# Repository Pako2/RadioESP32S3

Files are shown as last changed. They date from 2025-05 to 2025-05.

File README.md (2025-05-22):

# RadioESP32S3
## Introduction
&nbsp;&nbsp;&nbsp;&nbsp;Some time ago I published the [RadioESP32](https://github.com/Pako2/RadioESP32) project. It was intended exclusively for the basic ESP32 chips. I realized that it would be good to also try a variant with the more modern ESP32-S3 chip and this is the result. Since almost everything is identical to the original project, I will mainly emphasize the differences here.\
&nbsp;&nbsp;&nbsp;&nbsp;Complete project documentation can be found in the [UserGuide_EN.pdf](doc/UserGuide_EN.pdf) file.

## How to install
Experienced Tinkerers who have installed VS Code with PlatformIO supplement and normally use it probably do not need any other advice. Everything is described in the previous text. However, there may be some less experienced users who are interested in trying the project and do not need to make their own modifications. In this case, they can use pre-compiled binaries and install them in ESP32-S3 without VS Code/Platformio.
The procedure is as follows (valid only to Windows users):
1. The default assumption is that the development kit is connected to the USB port of your computer and you know the number of (virtual) COM port. Suppose it's a *COM10*. Use the connector marked *COM* (not *USB*) on the development kit.
2. Download the latest [RadioESP32S3_binaries.zip](https://github.com/Pako2/RadioESP32S3/releases/latest/download/RadioESP32S3_binaries.zip) and unpack the ZIP file to some suitable (work) folder.
3. In the selected folder, the **bin** folder appears that contains everything you need.
4. Open the command line window (**cmd.exe**) so that you are in the above folder **bin**.
5. Enter the **flash.bat** command. The following offer should appear:
<p float="left">
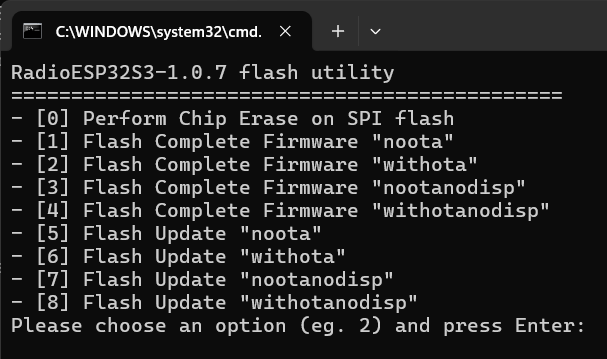
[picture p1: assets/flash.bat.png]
Flash menu
  
</p>

6. Select the desired firmware version (ie press the appropriate number) and then press Enter.
7. You will then be prompted to enter a COM port. Write the corresponding name (by example in point **1** it would be *COM10*) and press Enter.
8. There should be installed the necessary SW into ESP32.
9. After completion you can continue according to the **First start** chapter.

<ins>Note:</ins>\
The *withota* and *withotanodisp* versions are intended for production use, while the *noota* and *nootanodisp* versions are intended primarily for the development phase (as they allow comfortable editing of web server files). However, there is nothing to prevent the *noota* and *nootanodisp* versions from being used for production use as well.

## First start
When the device is started for the first time, it runs in default settings and in AP mode. On the PC, connect to the **RadioESP32S3** network and in the browser to the address **192.168.4.1**. A web page should appear through which the device settings need to be made.

## Design of the device
The circuit diagram and printed circuit board were created using the Eagle design system.
### Wiring diagram
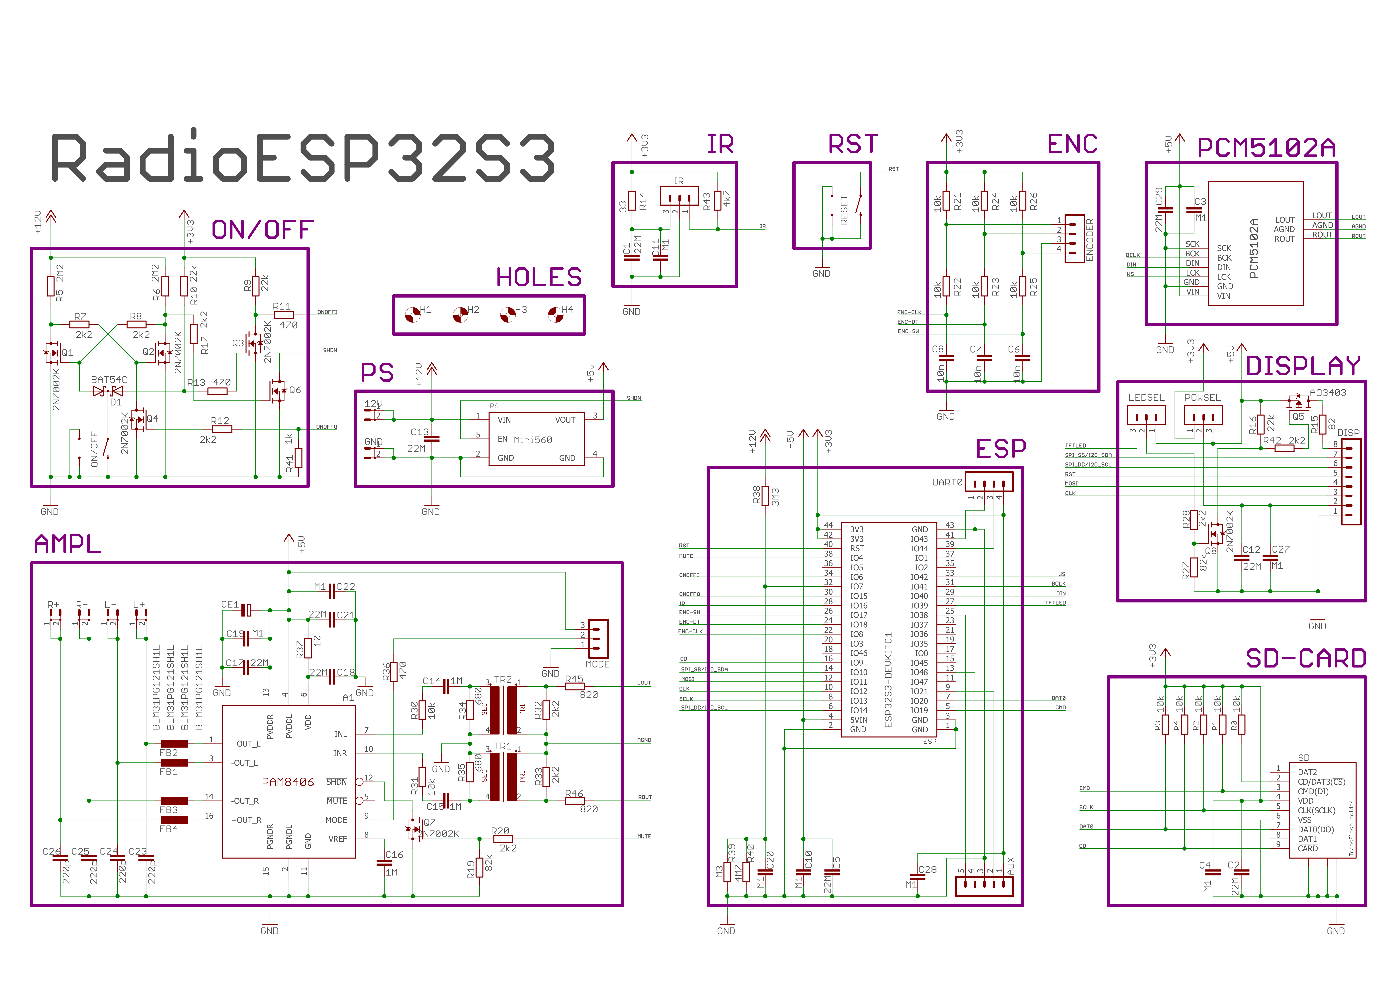
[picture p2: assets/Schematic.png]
Wiring diagram

### Printed circuit board
<p float="left">
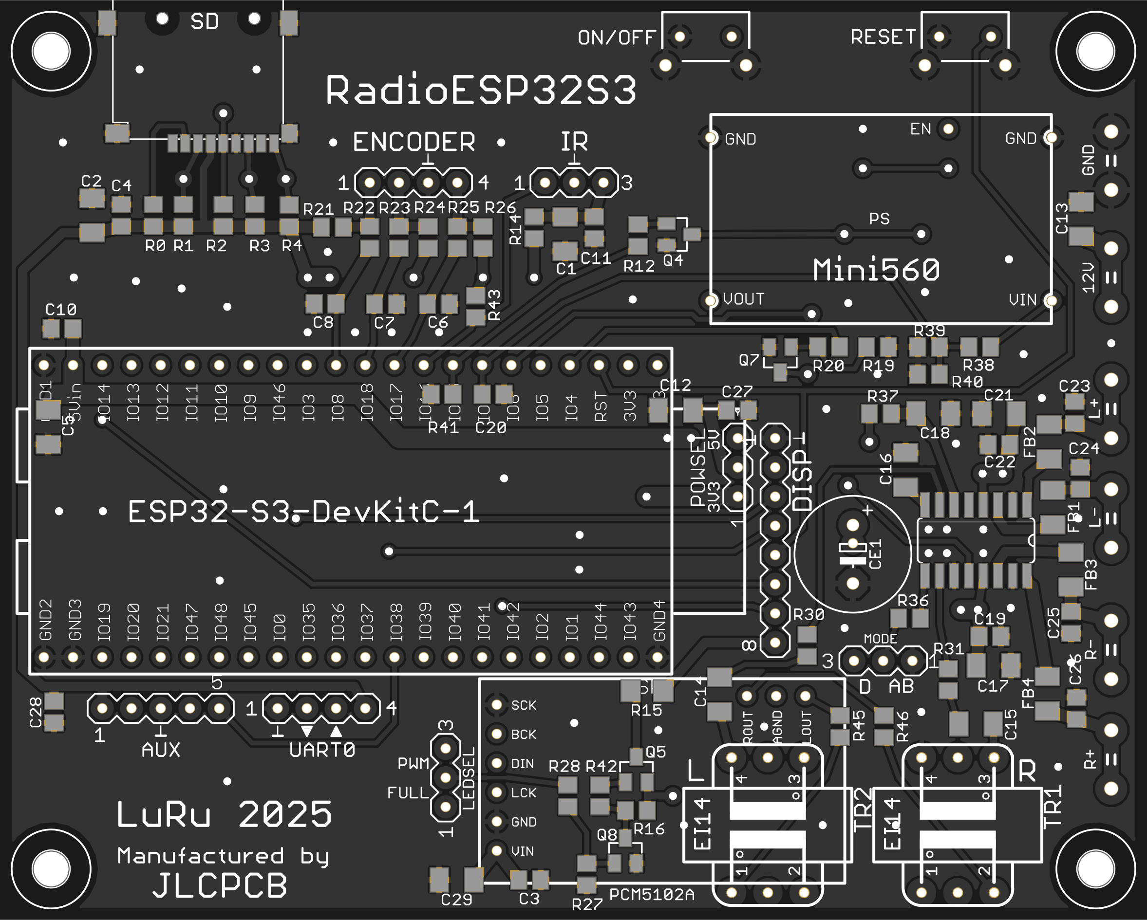
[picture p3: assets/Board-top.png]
PCB top side
  
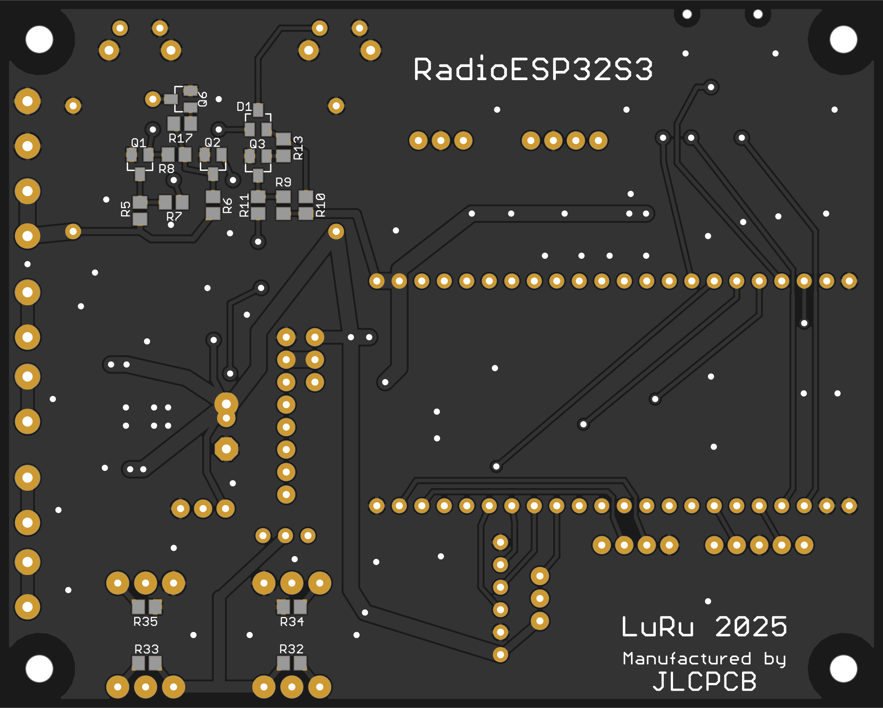
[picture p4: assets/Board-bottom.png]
PCB bottom side
   
</p>

## Choice of components
The basis of the design is the development kit "ESP32-S3-DevKitC-1" (shorter wider version). The board must have at least 8MB of flash memory and 4MB of PSRAM memory.

<p float="left">
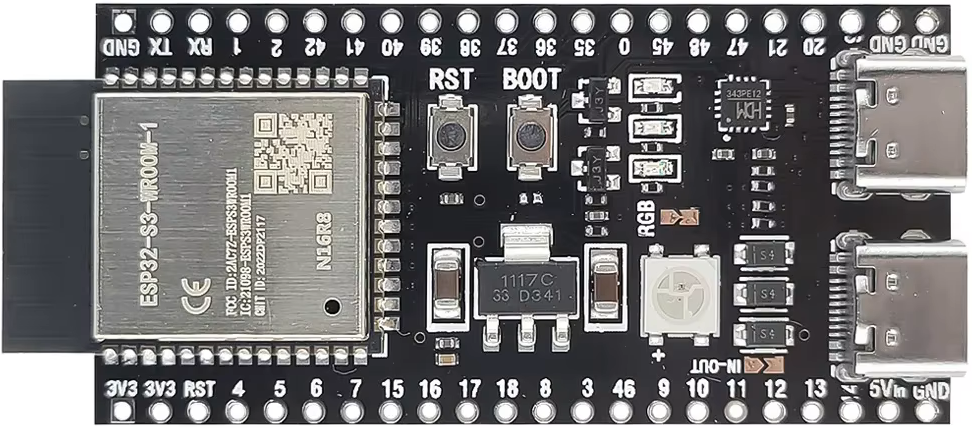
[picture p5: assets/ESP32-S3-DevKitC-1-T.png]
Development board - top side
   
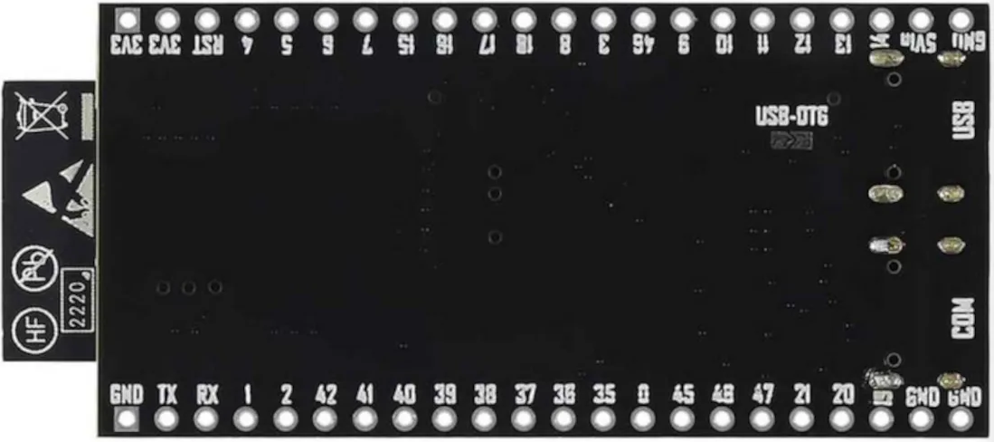
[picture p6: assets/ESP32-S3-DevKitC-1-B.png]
Development board - bottom side
   
</p>

## Choice of GPIO
I designed and used a PCB where the assignment of GPIOs for various functions is therefore fixed. But this is not fixed in the software. In fact, it is the opposite, most GPIOs can be selected by the user, so it should be easy to use a different connection than the PCB I designed.
However, there are two exceptions:
1. Display connection - this must be set in the *platformio.ini* file before compilation.
2. Selection of ADC channel for battery measurement (I chose channel adc1-6, which corresponds to GPIO 7)

<ins>Note:</ins>\
In the original design with the ESP32 base chip, there is a third exception - connecting an SD card in SD_MMC mode. Fortunately, there is no such exception here, because in this case (ESP32-S3 chip) any GPIO pin can be used. This is of course a huge advantage, because the problems that were with the ESP32 base chip (there GPIO2, which is one of the bootstrapping pins, had to be used) have disappeared.

## Assembled board
Finally, you can see a few pictures of the printed circuit board completely assembled and including the installed subboards (ESP32 development kit and DAC). I also added one photo of the finished radio (without the cover).

PCB 1
PCB 2
PCB 3
PCB 4
PCB 5
PCB 6
RADIO

### License
The code parts written by the author of the **RadioESP32S3** project are licensed under [GPL-3.0](LICENSE), 3rd party libraries that are used by this project are licensed under different license schemes, please check them out as well.

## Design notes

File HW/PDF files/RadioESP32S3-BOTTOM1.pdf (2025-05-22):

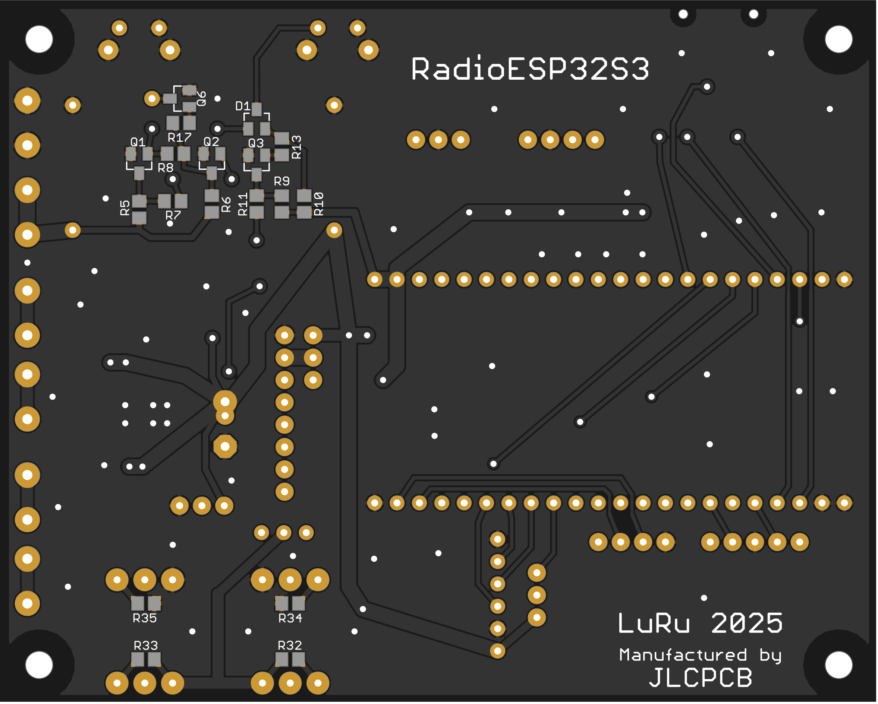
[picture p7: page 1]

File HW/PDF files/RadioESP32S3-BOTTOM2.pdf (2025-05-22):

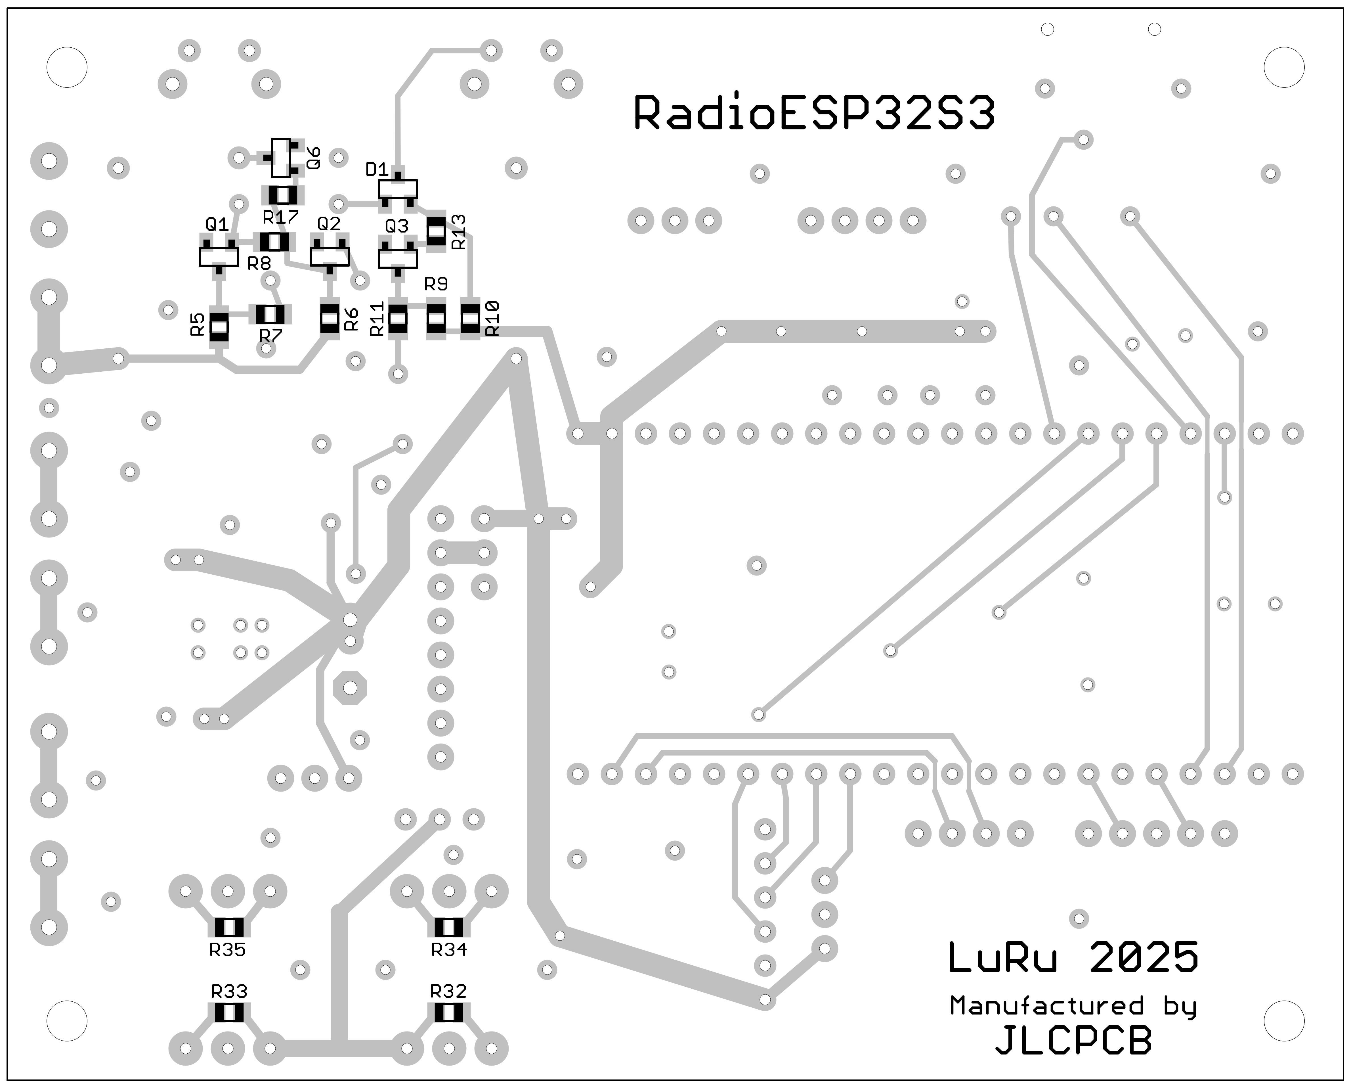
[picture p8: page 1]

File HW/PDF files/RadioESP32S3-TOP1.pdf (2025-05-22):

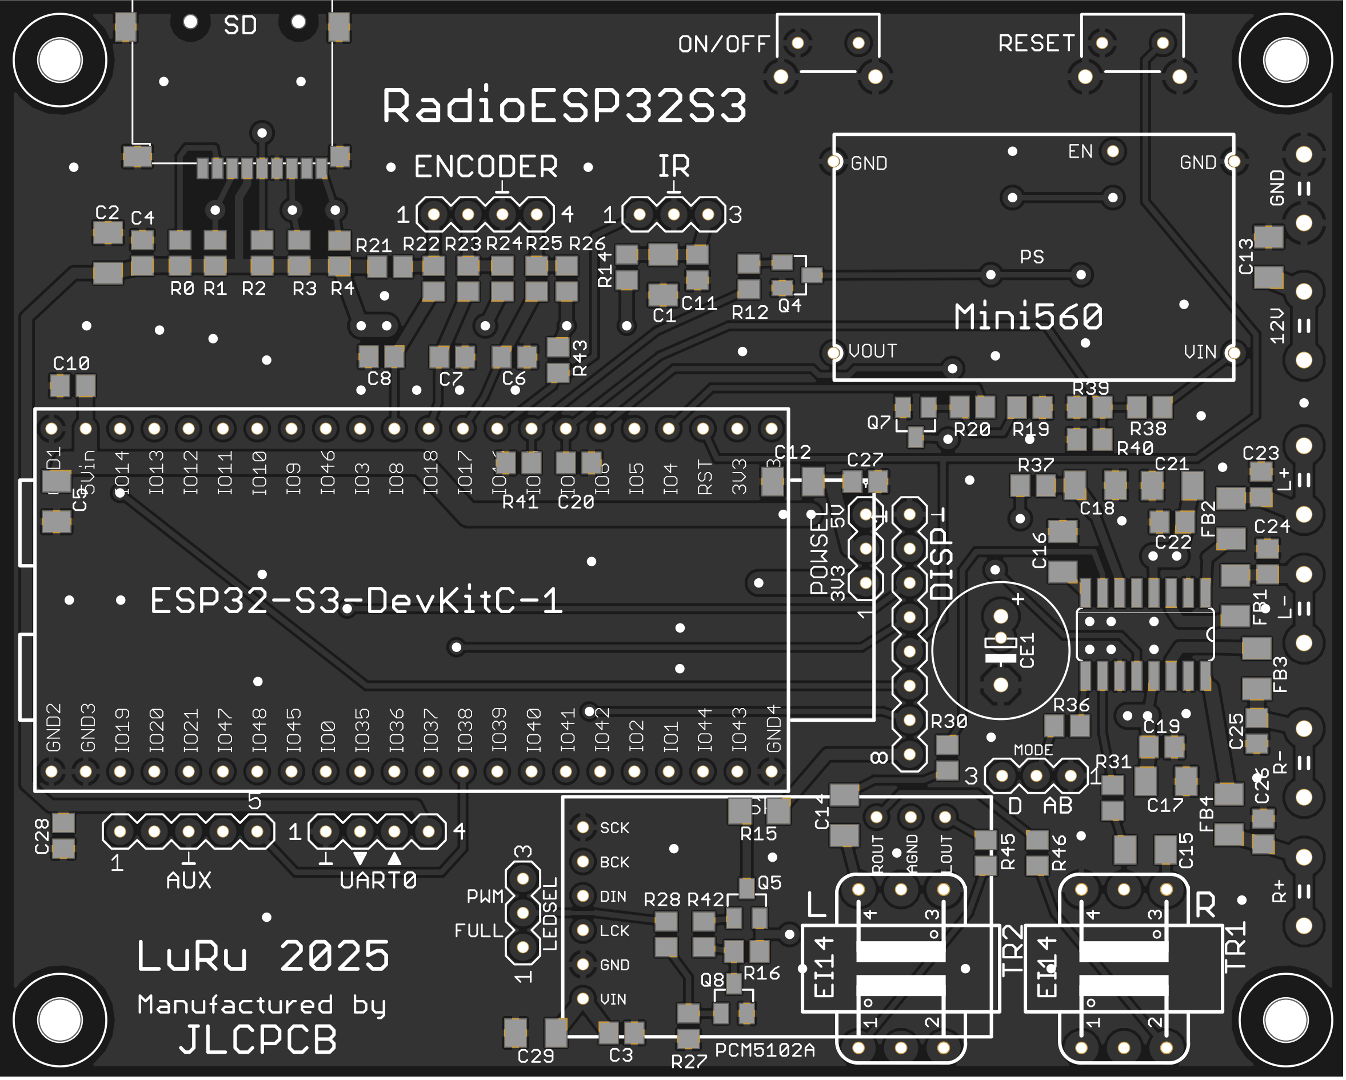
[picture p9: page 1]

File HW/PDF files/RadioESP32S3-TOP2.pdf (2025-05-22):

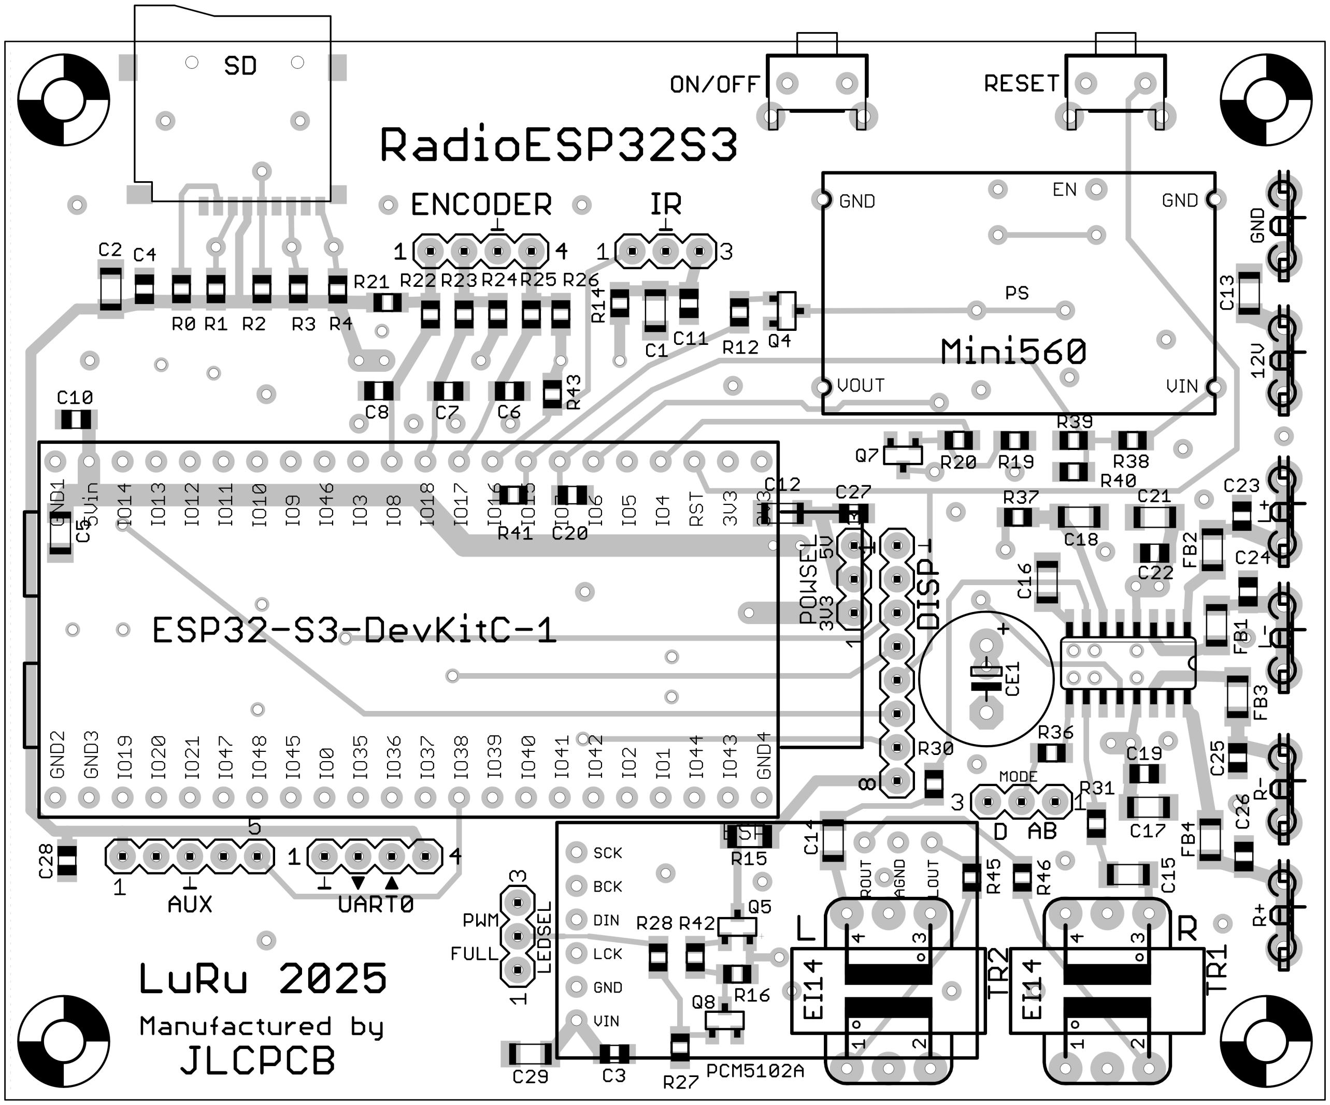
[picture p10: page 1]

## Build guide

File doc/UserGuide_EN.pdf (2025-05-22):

## RadioESP32S3

## Introduction

First of all, it is worth mentioning that this project would probably never have been created without the popular project "ESP32Radio-V2" by Edzelf. I am very grateful to the author for it and thank him for his work. Originally, of course, I took over the original project in its unchanged form, but very soon it stopped being convenient for me. I especially disliked the fact that the display did not display characters with diacritics.
The second biggest problem for me was the functioning of the file player from the SD card. One of my requirements for the device was that it should allow listening to audiobooks. In this case, however, the files need to be played in a defined (i.e. alphabetical) order. But that did not work with the original SW. After copying the files from the HDD to the SD card, the files were always arranged in a kind of random order and listening to the individual parts in the correct order was very complicated (the correct part had to be selected manually).
In addition to the two problems mentioned above, there were a number of other small things that I imagined to work differently. For example, I can mention a function that ensured that the last station listened to was always played after switching on (and with the last volume level used). But that did not suit me at all, I prefer that a default station (with the default volume) be played after switching on the device. I also planned to add some new functions that the original design did not have. In particular, I wanted the radio to be able to be turned on and off by pressing one (same) button and for the radio to have a sleep function (i.e. automatic shutdown after a set time). Despite the above facts, I took over several things from the original "ESP32Radio-V2" project almost unchanged and my work was thus made easier.
The website design, the way the ESP32-S3 communicates with the computer (via a web browser), and a few other solutions (like how to upgrade or work with the configuration file) are taken from the esp-rfid project. I have used it in several projects and it exactly suits my needs and ideas.

## Development with VS Code and PlatformIO

I use VS Code/PlatformIO as a development environment. Using the platformio.ini file, it is possible to create several software variants by specifying or not specifying the so-called "build-flag". The DATAWEB, SDCARD, BATTERY, AUTOSHUTDOWN and OTA build-flags are particularly important.
- Using the DATAWEB build-flag, the SW is compiled in a version that has the web server files stored in the "LittleFS" file system area, while without the DATAWEB parameter, the SW is compiled in a version in which the web server files are stored in the program memory (using the PROGMEM attribute) in the form of variables. I call the first version „data“ for short, the second „webh“. The data variant is intended primarily for the development phase (but nothing prevents it from being used as a production one), while the webh variant is intended exclusively as a production one and it is more or less impossible to develop with it.
- Using the SDCARD build-flag, support for the SD card file player function is enabled. Without using the aforementioned build-flag, the device is only able to play radio stations.
- Using the BATTERY build-flag, support for the supply voltage measurement function is enabled. This is of course suitable in the case of battery power. The display then shows the charge level.
- Using the AUTOSHUTDOWN build-flag, the support of the function that allows the device to be turned on and off with one button and also the sleep function (adjustable automatic shutdown time) is enabled. Of course, the condition is that the HW is equipped with the necessary circuit.
- Using the OTA build-flag, the function that allows a comfortable upgrade from the web interface is enabled. See the Upgrade chapter.
4 types of “envs” are also prepared in the platformio.ini file. With them, you can select both the SW variant (development, i.e. data – without OTA and production, i.e. webh – including OTA) and the variant with or without display. So, 4 combinations in total (noota, withota, nootanodisp and withotanodisp). The relevant “env” version is selected by commenting/uncommenting in the [platformio] section.
- 1 -

Using the DATAWEB build-flag, I proceed as follows when developing the SW:
1) Development takes place exclusively in the software data variant (the DATAWEB build-flag is used in the platformio.ini file – „env“ is either noota or nootanodisp). After editing the source files, compilation is performed in the usual way and the device is upgraded via the USB (serial) port.
2) If it is necessary to edit the *.html or *.js files of the web server to fix or add a function, you need to open the page http://<IP address of the device>/edit. For this to work, the PC must be connected to the Internet. The online library "ace" (Ajax.org Cloud9 Editor) is used for editing. For more information, see https://ace.c9.io/.
3) Once the required functionality has been achieved using steps 1 and 2, the webh variant of the software can be created. This is done by running the user script Download FS & Create WEBH, which is available via the PROJECT TASKS/<selected env version>/Custom menu. This will transform the web server files (from the LittleFS file system) into webh files. The utility "pio-esp32-esp8266-filesystem-downloader" by maxgerhardt is used to download the file system image and extract it.
4) Switch to webh variant (in the platformio.ini file, the build-flag DATAWEB needs to be removed [commented out] – „env“ is either withota or withotanodisp) and compile. The resulting image “firmware_WEBH_X.X.X.bin” (created during the compilation process) can be found in the /bin/<selected env version> directory. The version designation “X.X.X” is also set as a “build-flag” in the platformio.ini file before compilation.

## Upgrade

A device running the webh firmware variant can be upgraded very easily via the web interface. Procedure:
a) Select the Update item in the menu (on the left side of the screen).
b) A window will appear, showing the current version approximately in the middle.
c) Use the “Select file” button to search for the firmware file on your computer (e.g. firmware_WEBH_1.0.0.bin) and start the process with the Update button.
If everything goes well, the device will already contain the new software version after the restart.

## First start

When the device is started for the first time, it runs in default settings and in AP mode. On the PC, connect to the "RadioESP32S3" network and in the browser to the address 192.168.4.1. A web page should appear through which the device settings need to be made.

## Main menu

There is always the main menu on the left side of the screen. Description of the main menu items:

Radio Player
After clicking on this item, a page appears with which you can comfortably control the radio.

SD Card Player
This item is only displayed if the SW is compiled with the SDCARD option.
After clicking on this item, a page appears with which you can comfortably control the functions of the SD Card Player.
Status
Clicking on this item will bring up a page with basic device information.
- 2 -

Settings
If you need to adjust the device settings (for example, when you first start it), select Settings. Clicking on it will expand the menu and you will see eight submenus:

Radio Settings
This page is used to create a radio station menu. You can also set the default station (it is always automatically selected when the device is turned on), the default volume, and the values of a simple equalizer.

SD Card Settings
This item is only displayed if the SW is compiled with the SDCARD option. Only one parameter can be set on this page, and that is "Seek step". This is the length of the jump (forward and backward) in seconds. The default volume and equalizer settings on the Radio Settings page also apply to the SD card file player.
Network Settings
On this page, you need to set the network (or multiple networks) to which the device is to connect. Click Edit Networks and then New Network. In the dialog box that appears, set the required values. You can use the Scan button to search for available networks. After setting, click Save Changes. Under the network table, you can also change the SSID, IP address and mask (all in AP mode). You need to confirm the changes by clicking the Save button and then the yellow button with the text You have uncommited changes, please click here to commit and reboot …. However, this yellow button should only be used after going through all other settings, because after using it, the device will restart.

Hardware Settings
On this page it is possible to set some used GPIO pins (some are set before compilation in platformio.ini) and several other parameters. The set values must be confirmed again by pressing the Save button.

IR Remote Settings
This page is where you configure the remote control commands. Adding a new command is very simple and intuitive. The set commands must be confirmed again by pressing the Save button.

Display Settings

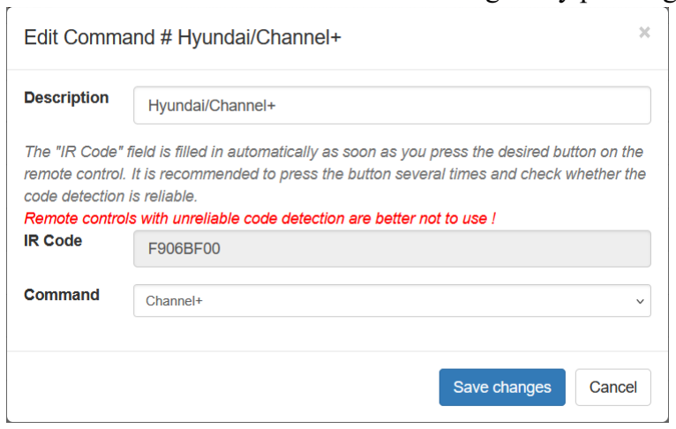
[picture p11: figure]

On this page, it is possible to set, in particular, the display backlight levels and the clock display settings in idle mode. The user can also name the days of the week in their own language (the names are English by default). As always, after all changes, the Save button must be pressed.

General Settings
On this page you can set the "Host Name" and also calibrate the battery level display. Confirm by pressing the Save button again.
- 3 -

NTP (Time) Settings
On this page you can set the NTP server, synchronization interval (in minutes) and time zone. Changes are confirmed again by pressing the Save button.
Sometimes it may happen that at the time of switching on (or restarting) the device none of the known WiFi networks are available. Then of course it is not possible to synchronize the time with the NTP server. In such an extreme situation the Sync Browser Time to Device button will help.

Backup & Restore
In the main menu we will also find the item “Backup & Restore”. The meaning is obvious from the name. It is possible to save a file with a backup of the settings to the PC and, if necessary, easily return to the same settings. Under the mentioned item there is another function – reboot the device.

Factory reset
This main menu item hides a function of the same name. After activating it, the configuration file is deleted and after rebooting the device is in the same state as when it was first started.

Update
This item is displayed only if the SW was compiled with the OTA build-flag, i.e. in the case of "envs" withota and withotanodisp. The procedure is described above in the Upgrade paragraph.

## Device design

The circuit diagram and printed circuit board were created using the Eagle design system.

Circuit diagram


- 4 -

Printed circuit board

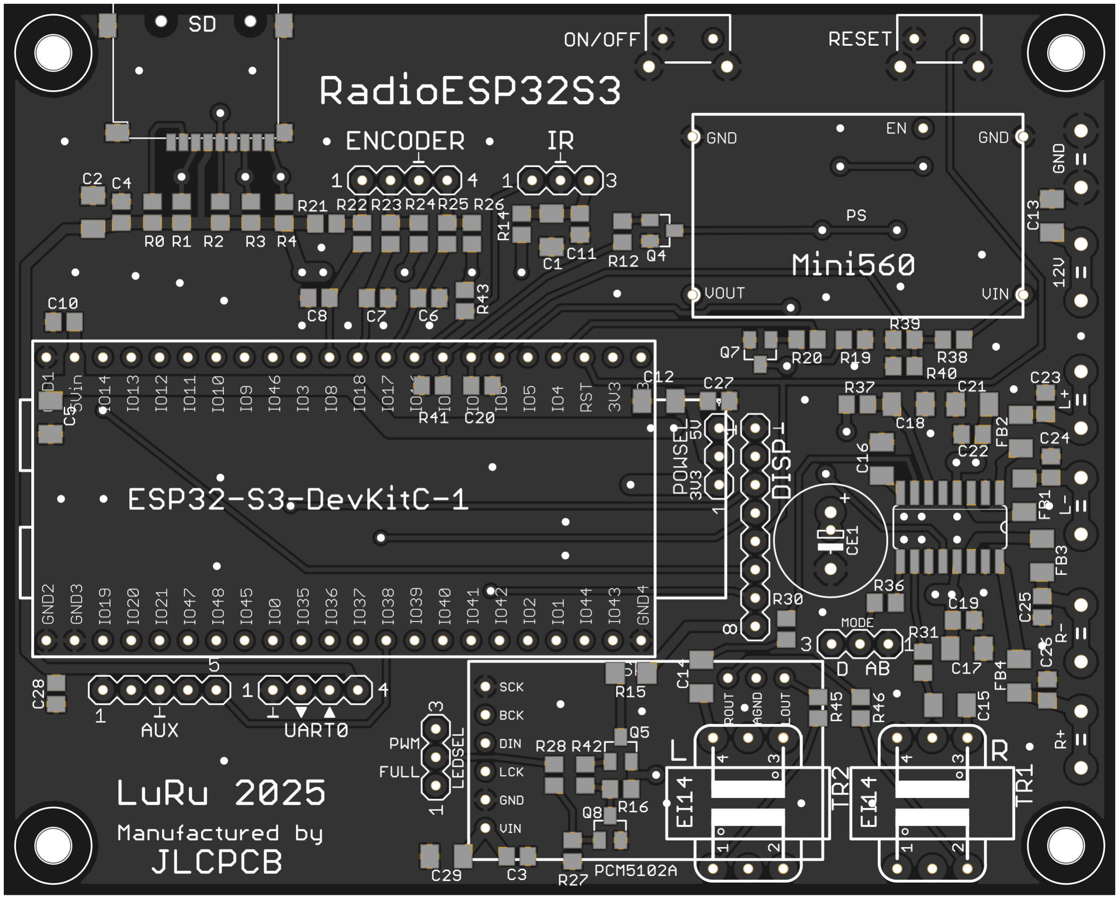
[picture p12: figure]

Component selection

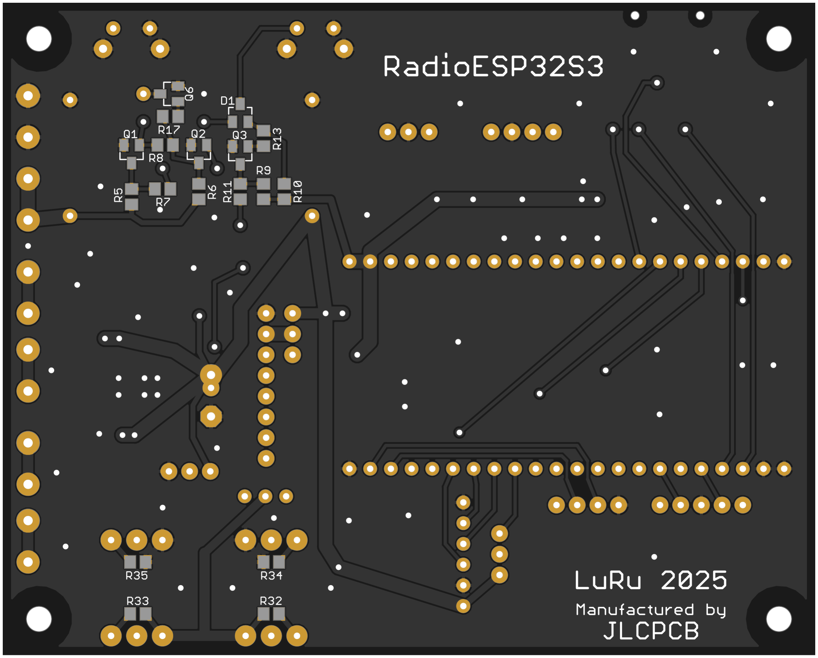
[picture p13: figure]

In the first phase of development, I used the VS1053 module (as a DAC) following Edzelf's example. It worked well, but I found this solution unnecessarily expensive and quite problematic (for example, I once accidentally bought a VS1003 instead and it didn't work well). That's why I completely abandoned this path and switched exclusively to a solution with I2S. As the basis for the SW, I chose the excellent "ESP32-audioI2S" library from the author shreibfaul1. This led to the need to use a type of ESP32-S3 development kit that is equipped with PSRAM memory (without this memory, no more complex project can be created with the "ESP32-audioI2S" library, you will soon run out of RAM) and flash memory of at least 8MB (to be able to upgrade via OTA). For this reason, I chose a development kit of the ESP32-S3-DevKitC-1 type.

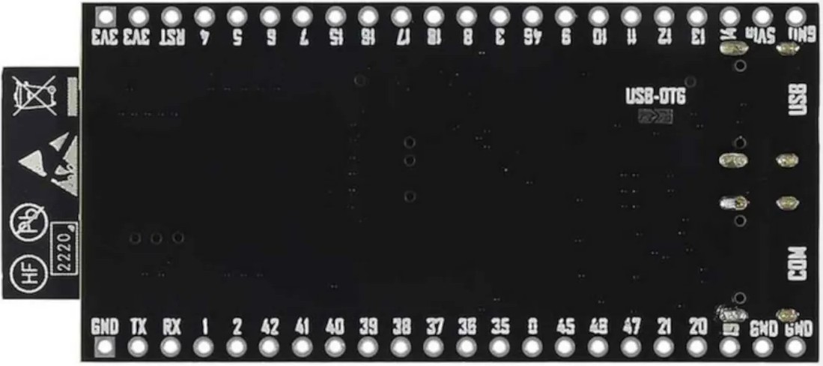
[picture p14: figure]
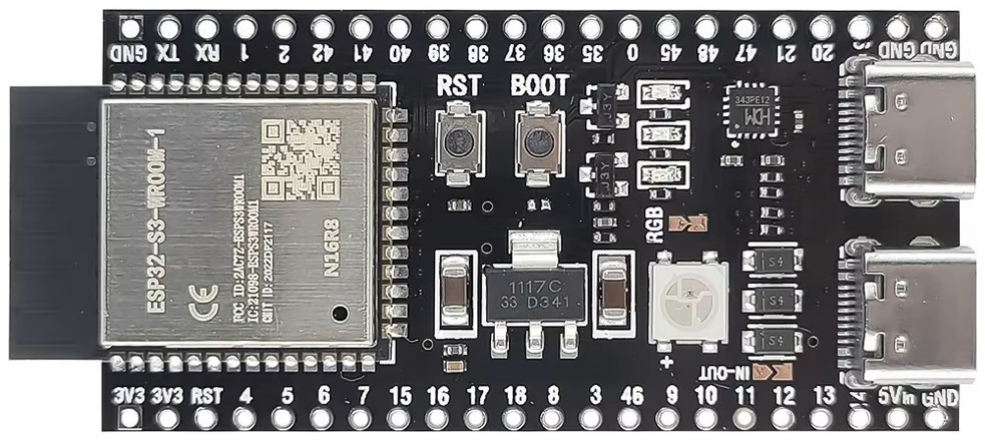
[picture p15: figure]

I decided that the basic supply voltage of the device will be 12V, because it can be very well implemented with three 18650 Li-ion cells. However, the development kit requires a voltage of 5V (as well as some other components) and therefore it is necessary to use a suitable step-down module. I chose the Mini560 module, which is sufficiently dimensioned (both voltage and current) and is equipped with an EN input (necessary for my needs).

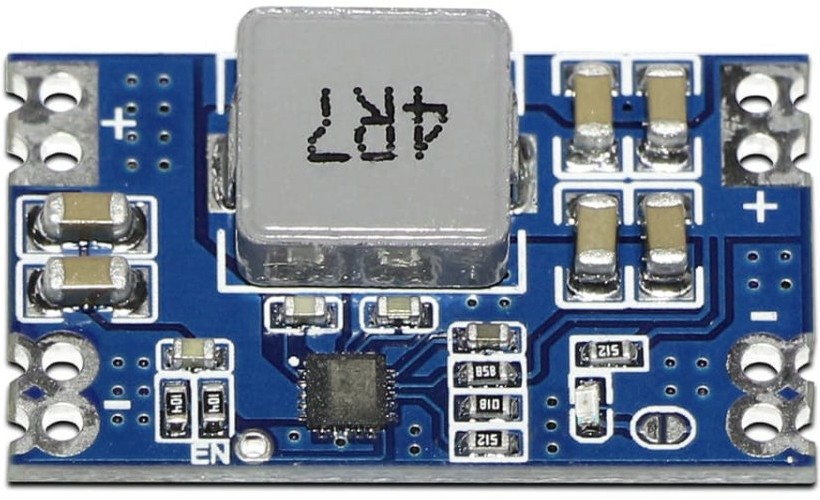
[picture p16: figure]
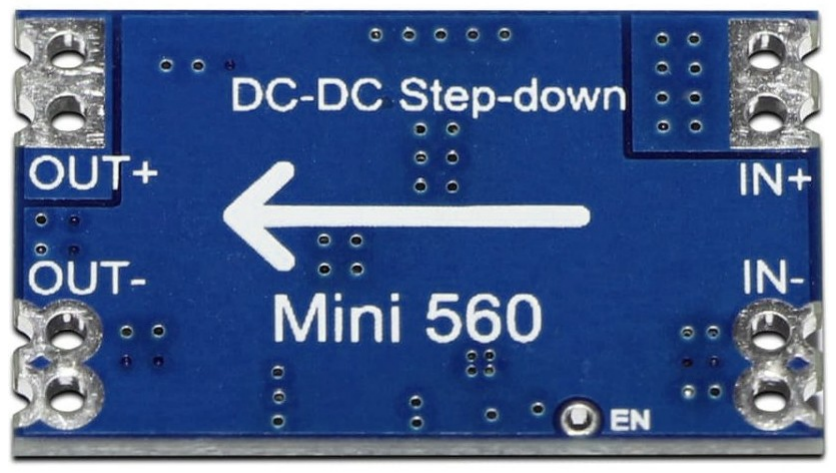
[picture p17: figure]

- 5 -

Originally (like Edzelf) I kept the option to choose between OLED and TFT display when compiling the software. But I finally gave up and OLED displays are no longer supported at all. So there are only two options - either a TFT display or none. I used a display with a diagonal of 1.77 inches and a resolution of 160x128. However, it should not be a problem to use any other one, supported by the TFT_eSPI library.

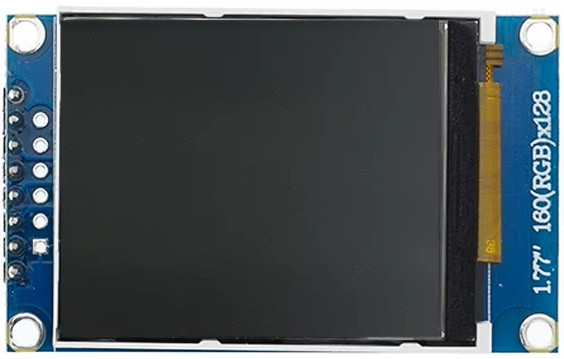
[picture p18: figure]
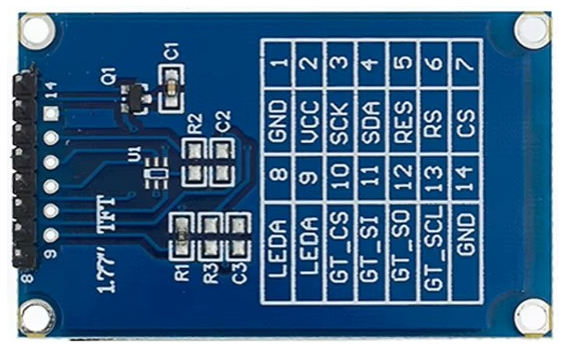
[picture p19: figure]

The essential part of the device is the digital-to-analog converter. I chose a module with the PCM5102A chip, which suited me due to its dimensions and also because the audio output is not only connected to a jack connector, but also to a pin header. This greatly simplifies the connection of the converter to the motherboard.

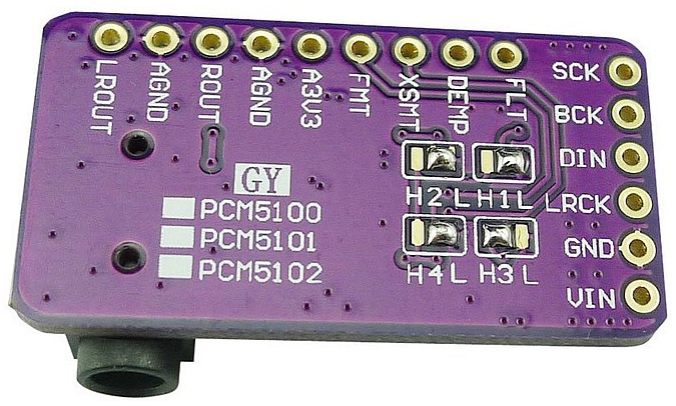
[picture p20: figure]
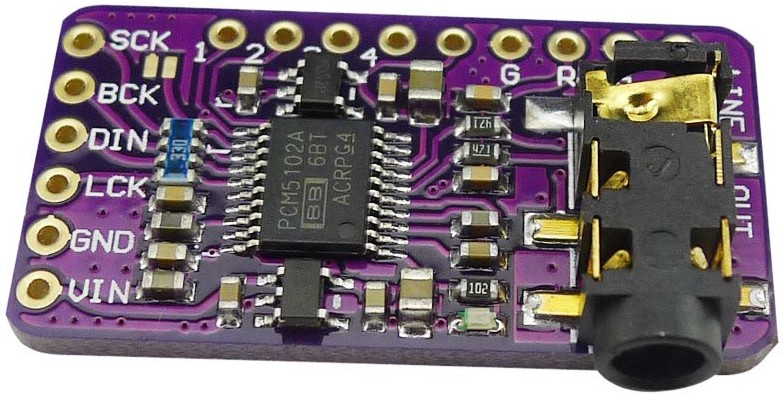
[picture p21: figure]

As an amplifier, I chose the PAM8406 type, which is powerful enough, works with a 5V supply voltage, and can be easily soldered by hand. This amplifier has one more advantage - it can operate in either class D or AB. I have kept the option of choosing on the printed circuit board as well - the mode is selected by placing the appropriate jumper.

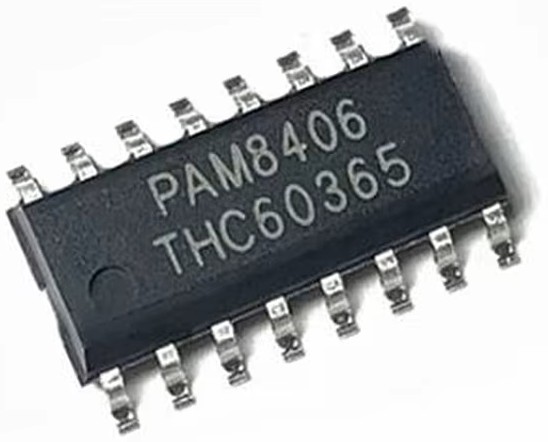
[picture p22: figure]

- 6 -

It is necessary to include isolation transformers between the DAC and the amplifier to break the ground loop and prevent unpleasant interference. I chose transformers that are only 9.1mm high and fit well between the converter board and the motherboard.

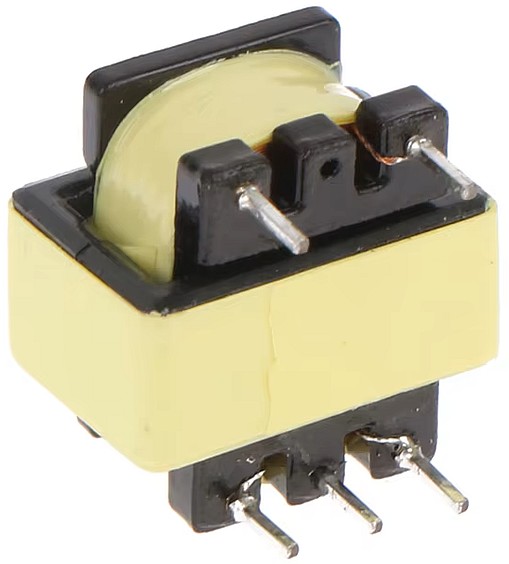
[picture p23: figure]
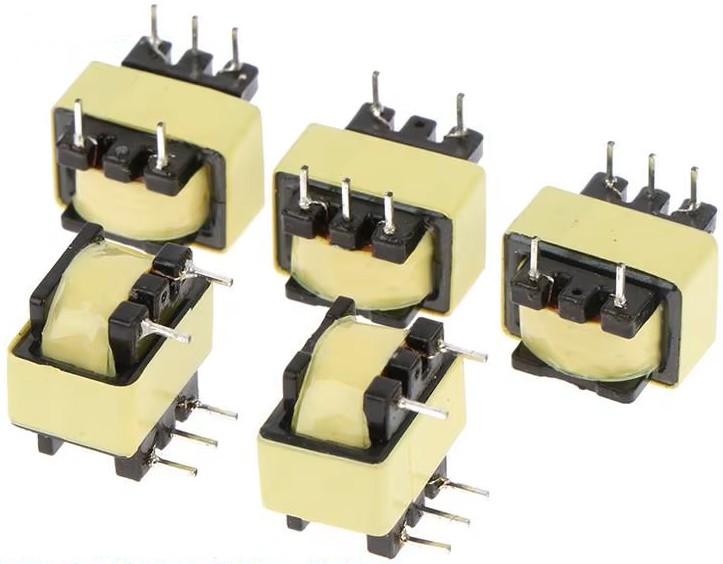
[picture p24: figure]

An important part of the device is also a rotary encoder. I used a completely common and cheap type EC11.
An obvious requirement for the device's function was also the possibility of control via infrared remote control. I tried the VS1838B type as a receiver and it worked well.
Finally, it was necessary to solve the method of connecting the supply voltage and speakers to the motherboard. I wanted to avoid terminal blocks with screws and therefore I chose faston connectors with a width of 4.8mm.

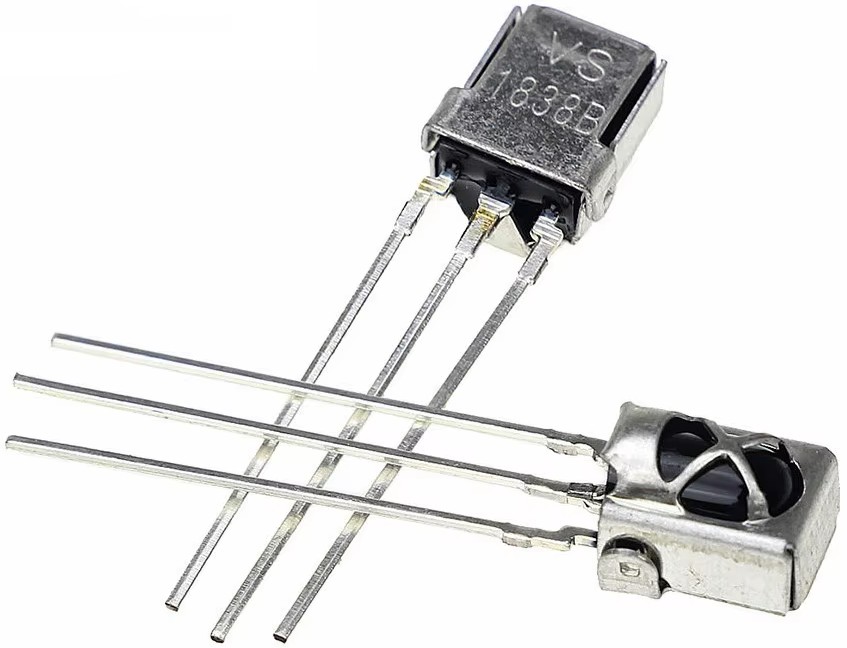
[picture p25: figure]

- 7 -

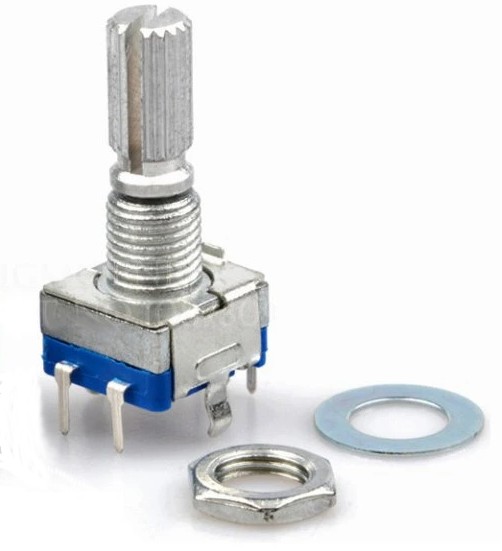
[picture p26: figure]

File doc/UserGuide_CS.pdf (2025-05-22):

## RadioESP32S3

## Úvod

Hned na úvod se sluší uvést, že tento projekt by asi nikdy nevznikl bez populárního projektu "ESP32Radio-V2" od Edzelf. Autorovi jsem za něj velice vděčný a děkuji mu za jeho práci. Původně jsem samozřejmě převzal originální projekt v nezměněné podobě, ale velice brzy mi to přestalo vyhovovat. Zejména mi vadilo, že displej nezobrazoval znaky s diakritikou.
Druhým největším problémem pro mne bylo fungování přehrávače souborů z SD karty. Jedním z mých požadavků na přístroj bylo, aby umožňoval poslech audioknih. V takovém případě je ale třeba, aby soubory byly přehrávány v definovaném (tedy abecedním) pořadí. Ale to s originálním SW nefungovalo. Po překopírování souborů z HDD na SD kartu se totiž soubory vždy seřadily v jakémsi náhodném pořadí a poslouchat jednotlivé díly ve správném pořadí tak bylo velmi komplikované (správný díl bylo nutné volit ručně).
Kromě uvedených dvou problémů tu pak byla ještě celá řada různých maličkostí, jejichž fungování jsem si představoval jinak. Jako příklad mohu uvést funkci, která zajišťovala, že po zapnutí se vždy přehrávala naposledy poslouchaná stanice (a navíc s naposledy použitou úrovní hlasitosti). To mně ale vůbec nevyhovovalo, já preferuji aby se po zapnutí přístroje přehrávala nějaká defaultní stanice (defaultní hlasitostí). Dále jsem plánoval přidat nějaké nové funkce, které originální konstrukce neměla. Zejména jsem chtěl, aby rádio bylo možné zapnout a vypnout stiskem jednoho (stejného) tlačítka a aby rádio mělo funkci usínání (tedy automatického vypnutí po nastaveném čase).
I přes uvedené skutečnosti jsem z originálního projektu "ESP32Radio-V2" převzal několik věcí téměř beze změny a moje práce tak byla usnadněna.
Design webových stránek, způsob komunikace mezi ESP32-S3 a počítačem (prostřednictvím webového prohlížeče) a několika dalších řešení (například způsob provádění upgrade nebo práce s konfiguračním souborem) jsou převzaty z projektu esp-rfid. Použil jsem to již v několika projektech a přesně to vyhovuje mým potřebám a představám.

## Vývoj s VS Code a PlatformIO

Jako vývojové prostředí používám VS Code/PlatformIO. Pomocí souboru platformio.ini je možné vytvořit několik variant software a to uvedením anebo neuvedením takzvaného „build-flagu“. Důležité jsou zejména build-flagy DATAWEB, SDCARD, BATTERY, AUTOSHUTDOWN a OTA.
- S použitím build-flagu DATAWEB se zkompiluje SW ve verzi, která má soubory webového serveru uložené v oblasti souborového systému „LittleFS“, zatímco bez parametru DATAWEB je SW zkompilován ve verzi, ve které soubory webového serveru jsou uložené v programové paměti (pomocí atributu PROGMEM) ve formě proměnných. První verzi říkám zkráceně „data“, druhé „webh“. Varianta data je určena především pro fázi vývoje (ale nic nebrání používat to i jako produkční), zatímco varianta webh je zamýšlena výhradně jako produkční a provádět s ní vývoj je víceméně nemožné.
- Použitím build-flagu SDCARD se zapíná podpora funkce přehrávače souborů z SD karty. Bez použití uvedeného build-flagu je přístroj schopen přehrávat pouze rozhlasové stanice.
- Použitím build-flagu BATTERY se zapíná podpora funkce měření napájecího napětí. Je to samozřejmě vhodné v případě napájení z baterií. Displej potom zobrazuje úroveň nabití.
- Použitím build-flagu AUTOSHUTDOWN se zapíná podpora funkce, umožňující zapínání a vypínání přístroje jedním tlačítkem a také funkce sleep (nastavitelná doba automatického vypnutí). Podmínkou je samozřejmě vybavení HW potřebným obvodem.
- Použitím build-flagu OTA se zapíná funkce, umožňující komfortní upgrade z prostředí webového rozhraní. Viz kapitola Upgrade.
V souboru platformio.ini jsou také připraveny 4 druhy “envs”. Pomocí nich lze vybrat jednak variantu SW (vývojová, tj. data – bez OTA a produkční, tj. webh – včetně OTA) a variantu s displejem anebo bez displeje. Celkem tedy 4 kombinace (noota, withota, nootanodisp a withotanodisp). Příslušná verze „env“ se volí zakomentováním/odkomentováním v části [platformio].
- 1 -

Za použití build-flagu DATAWEB postupuji při vývoji SW takto:
1) Vývoj probíhá výhradně ve variantě software data (v souboru platformio.ini je použit build-flag DATAWEB – „env“ je buď noota nebo nootanodisp). Po úpravě zdrojových souborů se obvyklým způsobem provede kompilace a přístroj se upgraduje přes USB (sériový) port.
2) Pokud je pro opravu nebo přidání nějaké funkce nutné upravit i soubory *.html nebo *.js webového serveru, je třeba otevřít stránku http://<IP adresa přístroje>/edit. Aby to fungovalo, PC musí být připojen na internet. K editování je totiž využívána online knihovna „ace“ (Ajax.org Cloud9 Editor). Více viz https://ace.c9.io/.
3) Jakmile se pomocí kroků 1 a 2 dosáhne požadované funkcionality, lze vytvořit webh variantu software. To se provede spuštěním uživatelského skriptu Download FS & Create WEBH, který je dostupný prostřednictvím nabídky PROJECT TASKS/<vybraná verze env>/Custom. Tím dojde k transformaci souborů webového serveru (ze souborového systému LittleFS) do souborů webh. Ke stažení obrazu souborového systému a jeho extrakci je použita utilita „pio-esp32-esp8266-filesystem-downloader“ od maxgerhardt.
4) Přepnutí na variantu webh (v souboru platformio.ini se nepoužije build-flag DATAWEB - „env“ je buď withota nebo withotanodisp) a provedení kompilace. Výsledný obraz „firmware_WEBH_X.X.X.bin” (vytvořený během procesu kompilace) lze nalézt v adresáři /bin/<vybraná verze env>. Označení verze „X.X.X“ se nastavuje před kompilací v souboru platformio.ini rovněž jako „build-flag“.

## Upgrade

Přístroj, ve kterém běží webh varianta firmware, může být upgradován velmi snadno prostřednictvím webového rozhraní. Postup:
a) V nabídce (na levé straně obrazovky) vybereme položku Update.
b) Objeví se okno, které přibližně uprostřed zobrazuje aktuální verzi.
c) Pomocí tlačítka „Vybrat soubor“ lze v počítači vyhledat soubor s firmwarem (např. firmware_WEBH_1.0.0.bin) a tlačítkem Update proces spustit.
Pokud vše proběhne v pořádku, po restartu již přístroj obsahuje novou verzi software.

## První spuštění

Jakmile je přístroj poprvé spuštěn, běží ve výchozím nastavení a v režimu AP. Na PC se připojíme k síti „RadioESP32S3“ a v prohlížeči na adresu 192.168.4.1. Měla by se objevit webová stránka prostřednictvím které je třeba provést nastavení přístroje.

## Hlavní nabídka

V levé části obrazovky je vždy hlavní nabídka. Popis položek hlavní nabídky:

Radio Player
Po kliknutí na tuto položku se objeví stránka, pomocí které se dá komfortně ovládat rádio.

SD Card Player
Tato položka se zobrazuje jen v případě, že SW je zkompilován s možností SDCARD.
Po kliknutí na tuto položku se objeví stránka, pomocí které se dají komfortně ovládat funkce přehrávače souborů z SD karty.
- 2 -

Status
Po kliknutí na tuto položku se objeví stránka se základními údaji o přístroji.

Settings
Je-li třeba upravit nastavení přístroje (například při prvním spuštění), vybereme položku Settings. Po kliknutí na ni se nabídka rozbalí a uvidíme osm dílčích nabídek:

Radio Settings
Na této stránce se zejména vytváří nabídka rozhlasových stanic. Dále se zde dá nastavit výchozí stanice (ta se vždy automaticky vybere při zapnutí přístroje), výchozí hlasitost a hodnoty jednoduchého ekvalizéru.

SD Card Settings
Tato položka se zobrazuje jen v případě, že SW je zkompilován s možností SDCARD. Na této stránce se dá nastavit pouze jeden parametr a tím je "Seek step". To je délka skoku (vpřed i vzad) ve vteřinách. Nastavení výchozí hlasitosti a ekvalizéru, které je na stránce Radio Settings, platí i pro přehrávač souborů z SD karty.
Network Settings
Na této stránce je třeba nastavit zejména síť (případně více sítí), na kterou se má přístroj připojit. Stiskneme Edit Networks a následně New Network. V dialogovém okně, které se objeví nastavíme požadované hodnoty. Lze použít tlačítko Scan k vyhledání dostupných sítí. Po nastavení stiskneme Save Changes. Pod tabulkou sítí je možné ještě změnit SSID, IP adresu a masku (vše v AP režimu). Změny je třeba potvrdit stisknutím tlačítka Save a posléze také žlutého tlačítka s textem You have uncommited changes, please click here to commit and reboot …. Toto žluté tlačítko je však vhodné použít teprve až po projití všech ostatních nastavení, protože po jeho použití se přístroj restartuje.

Hardware Settings
Na této stránce je možné nastavit některé použité GPIO piny (některé jsou nastaveny před kompilací v platformio.ini) a několik dalších parametrů. Nastavené hodnoty je opět třeba potvrdit stisknutím tlačítka Save.

IR Remote Settings
Na této stránce se konfigurují povely dálkového ovládání. Přidání nového povelu je velmi jednoduché a intuitivní. Nastavené povely je třeba opět třeba potvrdit stisknutím tlačítka Save.

Display Settings

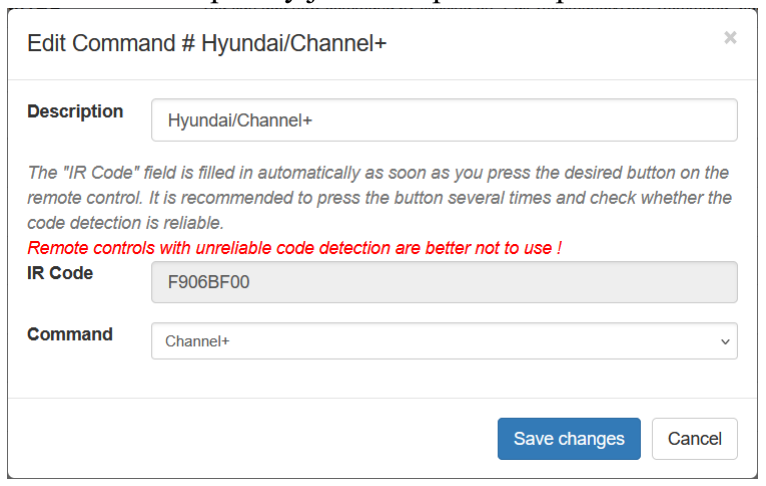
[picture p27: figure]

Na této stránce je možné nastavit zejména úrovně podsvícení displeje a nastavení zobrazení hodin v klidu. Uživatel si také může pojmenovat dny v týdnu ve svém jazyce (ve výchozím stavu jsou jména anglická). Jako vždy se po všech změnách musí stisknout tlačítko Save.

- 3 -

General Settings
Na této stránce je možné nastavit "Jméno stroje" (Host Name) a také se zde kalibruje zobrazování úrovně nabití baterie. Potvrzuje se opět stisknutím tlačítka Save.

NTP (Time) Settings
Na této stránce je možné nastavit NTP server, interval synchronizace (v minutách) a časovou zónu. Změny se opět potvrzují stisknutím tlačítka Save.
Někdy se může stát, že v době zapnutí (nebo restartu) přístroje není dostupná žádná ze známých WiFi sítí. Potom samozřejmě není možné synchronizovat čas s NTP serverem. V takové krajní situaci pomůže tlačítko Sync Browser Time to Device.

Backup & Restore
V hlavní nabídce dále nalezneme položku „Backup & Restore“. Význam je zřejmý z názvu. Je možné uložit si do PC soubor se zálohou nastavení a v případě potřeby se ke stejnému nastavení snadno vrátit. Pod uvedenou položkou je umístěna ještě další funkce – reboot přístroje.

Factory reset
Pod touto položkou hlavní nabídky se skrývá stejnojmenná funkce. Po její aktivaci se vymaže konfigurační soubor a po rebootu je přístroj ve stejném stavu jako při prvním spuštění.

Update
Tato položka se zobrazuje jen v případě, že SW byl zkompilován s build-flagem OTA, tedy v případě „envs“ withota a withotanodisp. Postup je popsán výše v odstavci Upgrade.

## Konstrukce přístroje

Schéma zapojení a plošný spoj byly vytvořeny pomocí návrhového systému Eagle.

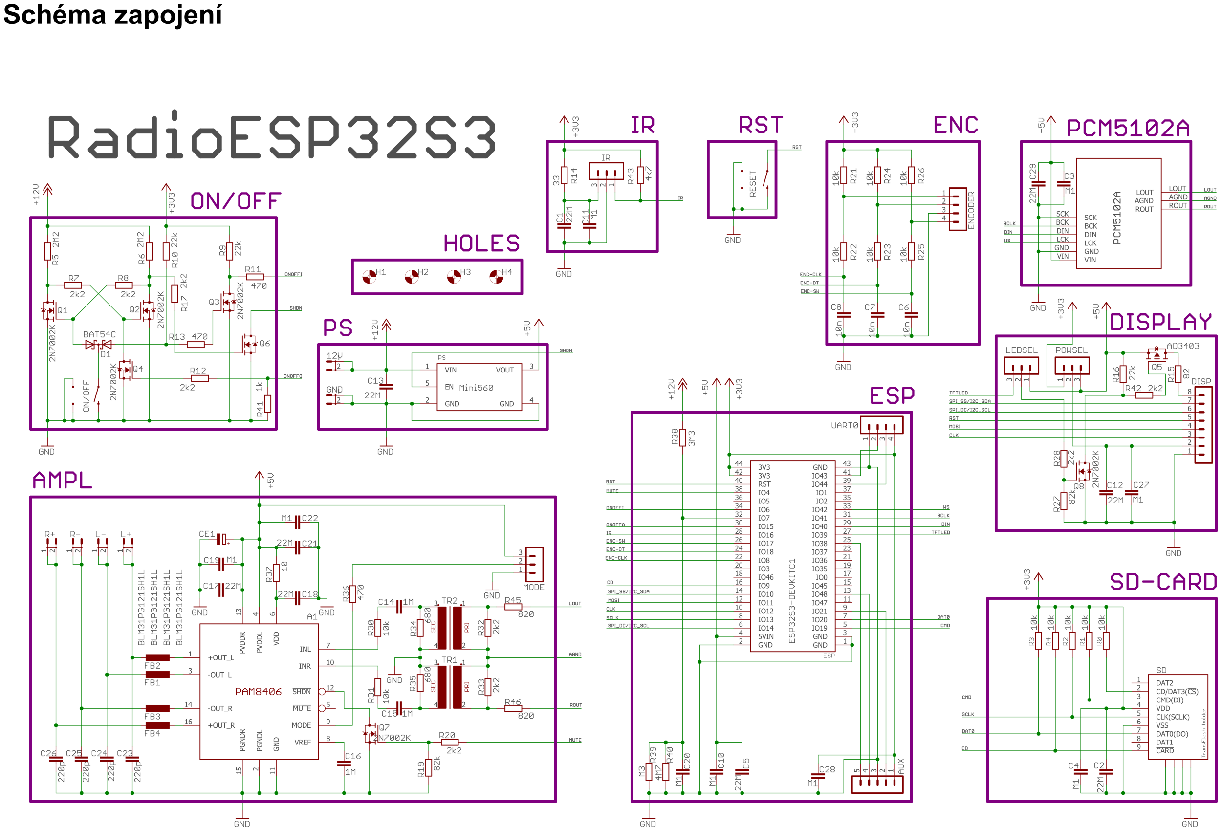
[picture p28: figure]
Schéma zapojení

- 4 -

Plošný spoj

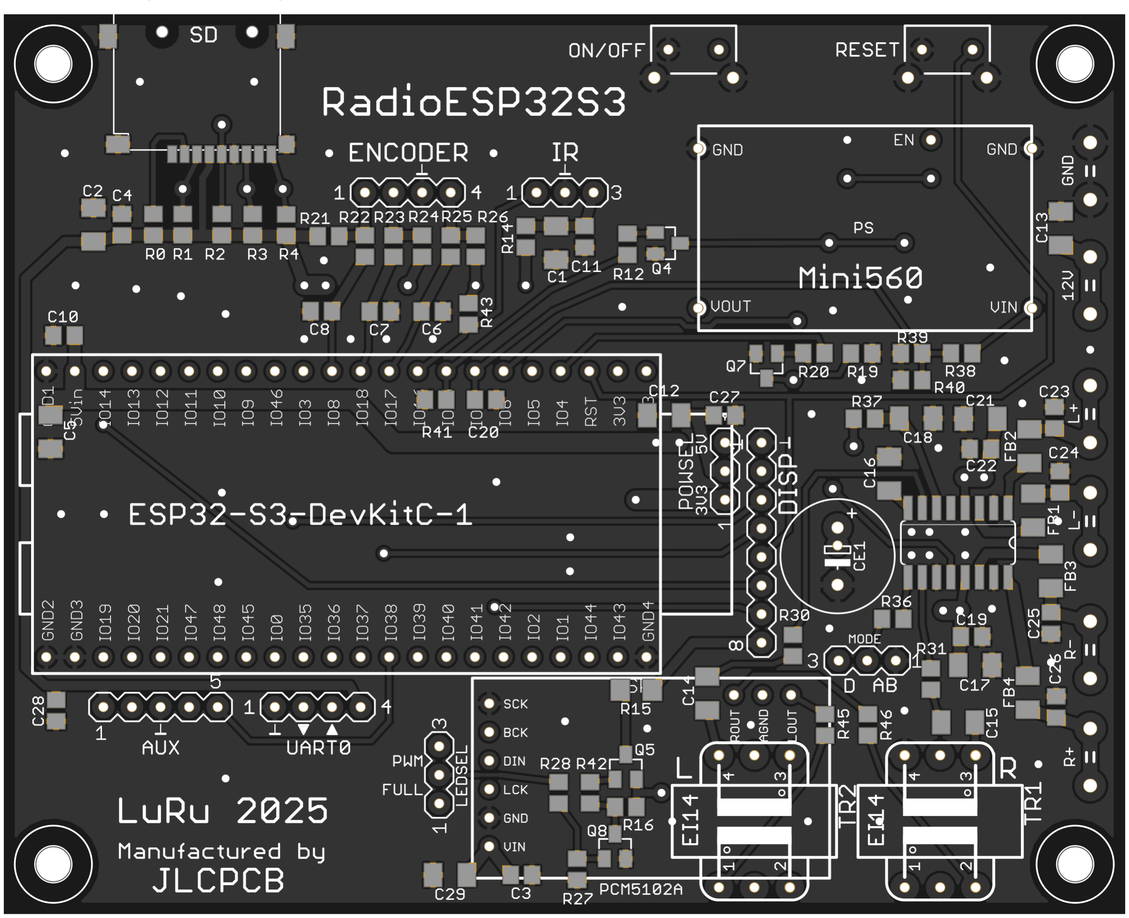
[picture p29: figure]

Volba součástek

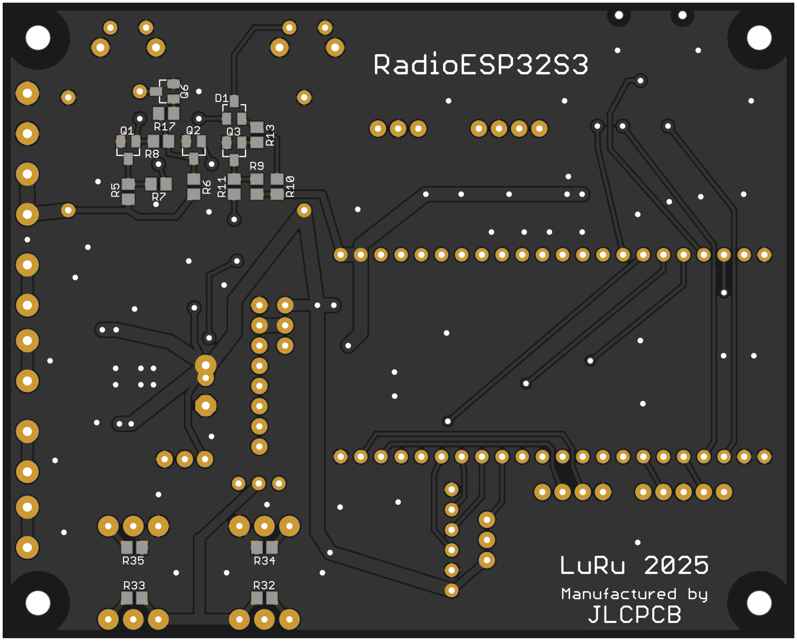
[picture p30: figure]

V první fázi vývoje jsem po vzoru Edzelf používal (jako DAC) modul VS1053. To sice fungovalo dobře, ale toto řešení mi připadalo zbytečně drahé a také dosti problematické (například jednou jsem omylem koupil VS1003 místo toho a to nefungovalo dobře). Proto jsem tuto cestu úplně opustil a přešel výhradně na řešení s I2S. Za základ SW jsem proto zvolil výbornou knihovnu "ESP32-audioI2S" od autora shreibfaul1. Z toho vyplynula potřeba použít takový typ vývojového kitu ESP32-S3, který je vybaven pamětí PSRAM (bez této paměti se totiž s uvedenou knihovnou nedá vytvořit žádný komlexnější projekt, brzy se narazí na nedostatek paměti RAM) a pamětí flash o velikosti minimálně 8MB (aby bylo možné upgradovat pomocí OTA). Z toho důvodu jsem zvolil vývojový kit typu ESP32-S3-DevKitC-1.

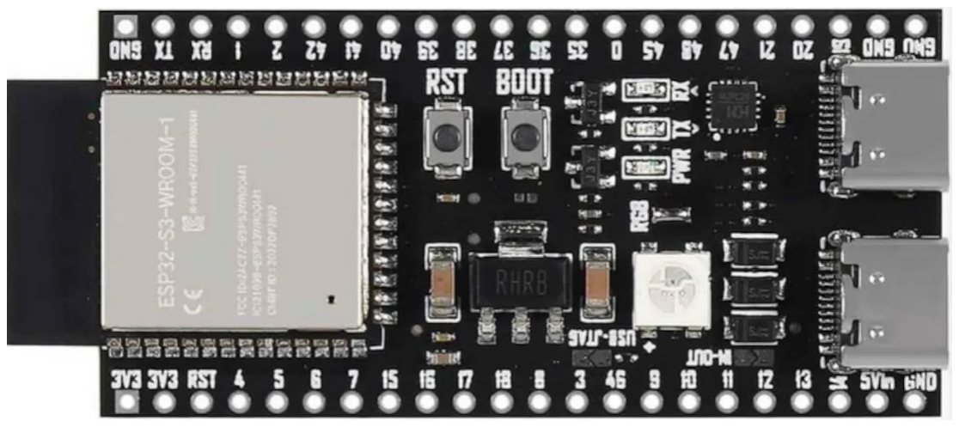
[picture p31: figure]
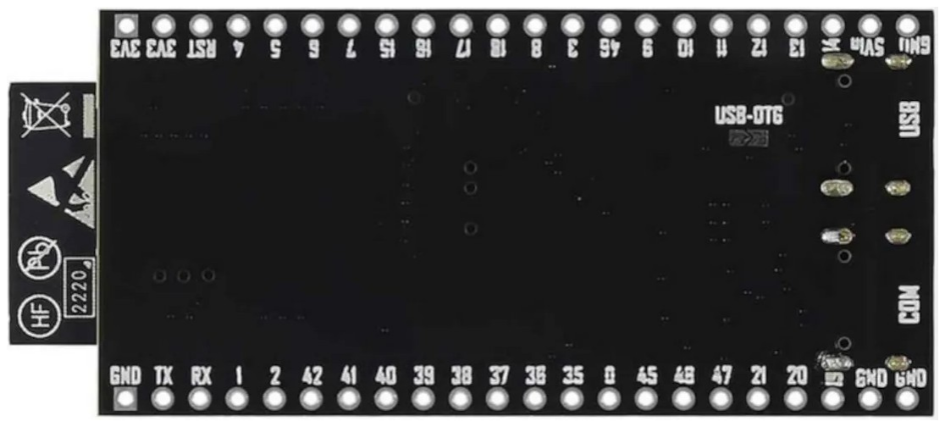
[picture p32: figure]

Rozhodl jsem se, že základní napájecí napětí přístroje bude 12V, protože může být velmi dobře realizováno třemi Li-ion články 18650. Vývojový kit však potřebuje napětí 5V (stejně jako některé další komponenty) a proto je třeba použít vhodný step-down modul. Zvolil jsem modul Mini560, který je dostatečně dimenzovaný (napěťově i proudově) a je vybaven (pro mé potřeby nezbytným) vstupem EN.

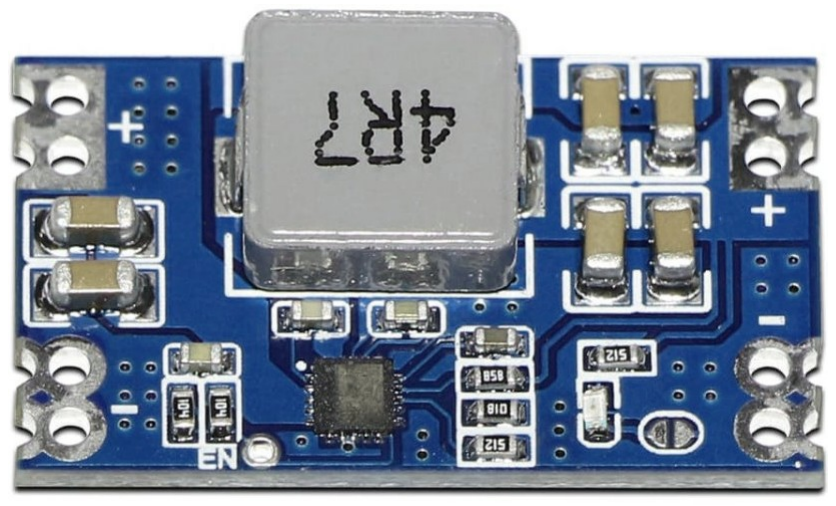
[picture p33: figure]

- 5 -

Původně jsem (stejně jako Edzelf) zachovával možnost při kompilaci SW vybrat si mezi displejem OLED a displejem TFT. Nakonec jsem od toho ale ustoupil a OLED displeje již nejsou vůbec podporovány. Možnosti volby jsou tedy jen dvě - buď displej typu TFT anebo žádný. Já jsem použil displej s úhlopříčkou 1,77 palce a rozlišením 160x128. Neměl by však být problém použít jakýkoliv jiný, podporovaný knihovnou TFT_eSPI.

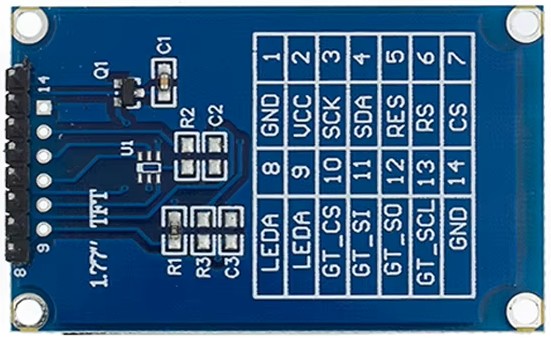
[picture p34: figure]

Podstatnou součástí přístroje je digitálně-analogový převodník. Zvolil jsem modul s čipem PCM5102A, který mi vyhovoval svými rozměry a také tím, že audio výstup je vyveden nejen na konektor typu jack, ale také na pinovou lištu. Tím se totiž velmi zjednodušuje propojení převodníku se základní deskou.

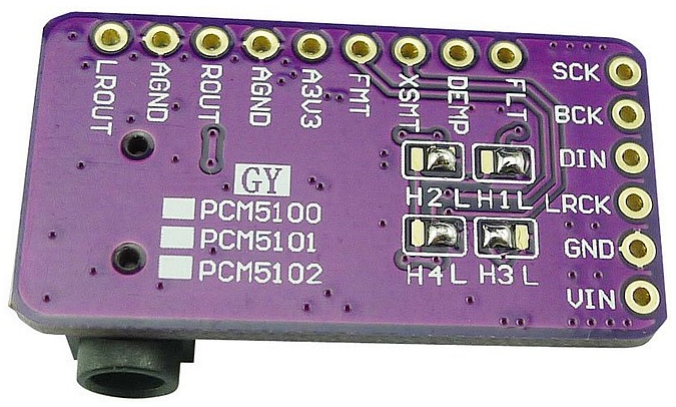
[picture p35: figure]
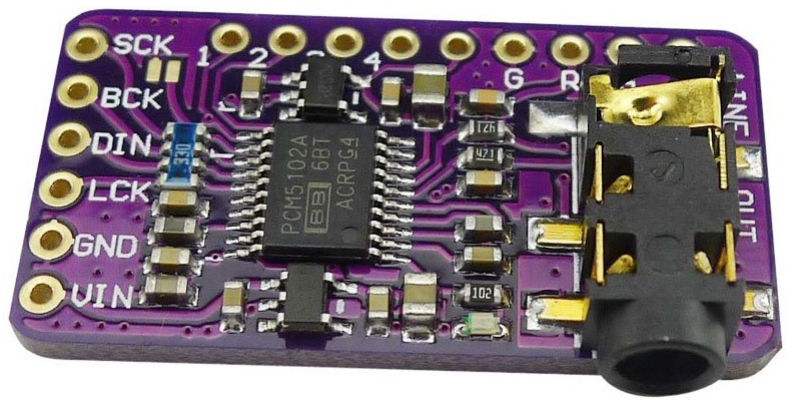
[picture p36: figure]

Jako zesilovač jsem vybral typ PAM8406, který je dostatečně výkonný, stačí mu napájecí napětí 5V a dá se dobře ručně pájet. Tento zesilovač má ještě jednu výhodu - může pracovat buď ve třídě D nebo AB. Já jsem zachoval možnost volby i na desce plošných spojů – režim se vybírá umístěním příslušného jumperu.


- 6 -

Mezi DAC a zesilovač je nutné zařadit oddělovací transformátory, aby se přerušila zemní smyčka a zabránilo se tak nepříjemnému rušení. Vybral jsem si transformátory, které mají výšku pouze 9.1mm a dobře se tak vejdou mezi desku převodníku a základní desku.


Důležitou součástí přístroje je rovněž rotační kodér. Použil jsem zcela běžný a levný typ EC11. Samozřejmým požadavkem na funkci přístroje byla také možnost ovládání pomocí infračerveného dálkového ovládání. Jako přijímač jsem vyzkoušel typ VS1838B a osvědčil se.
Nakonec bylo třeba vyřešit ještě způsob připojení napájecího napětí a reproduktorů na základní desku. Chtěl jsem se vyhnout svorkovnicím se šroubky a proto jsem zvolil konektory typu faston šířky 4,8mm.


- 7 -


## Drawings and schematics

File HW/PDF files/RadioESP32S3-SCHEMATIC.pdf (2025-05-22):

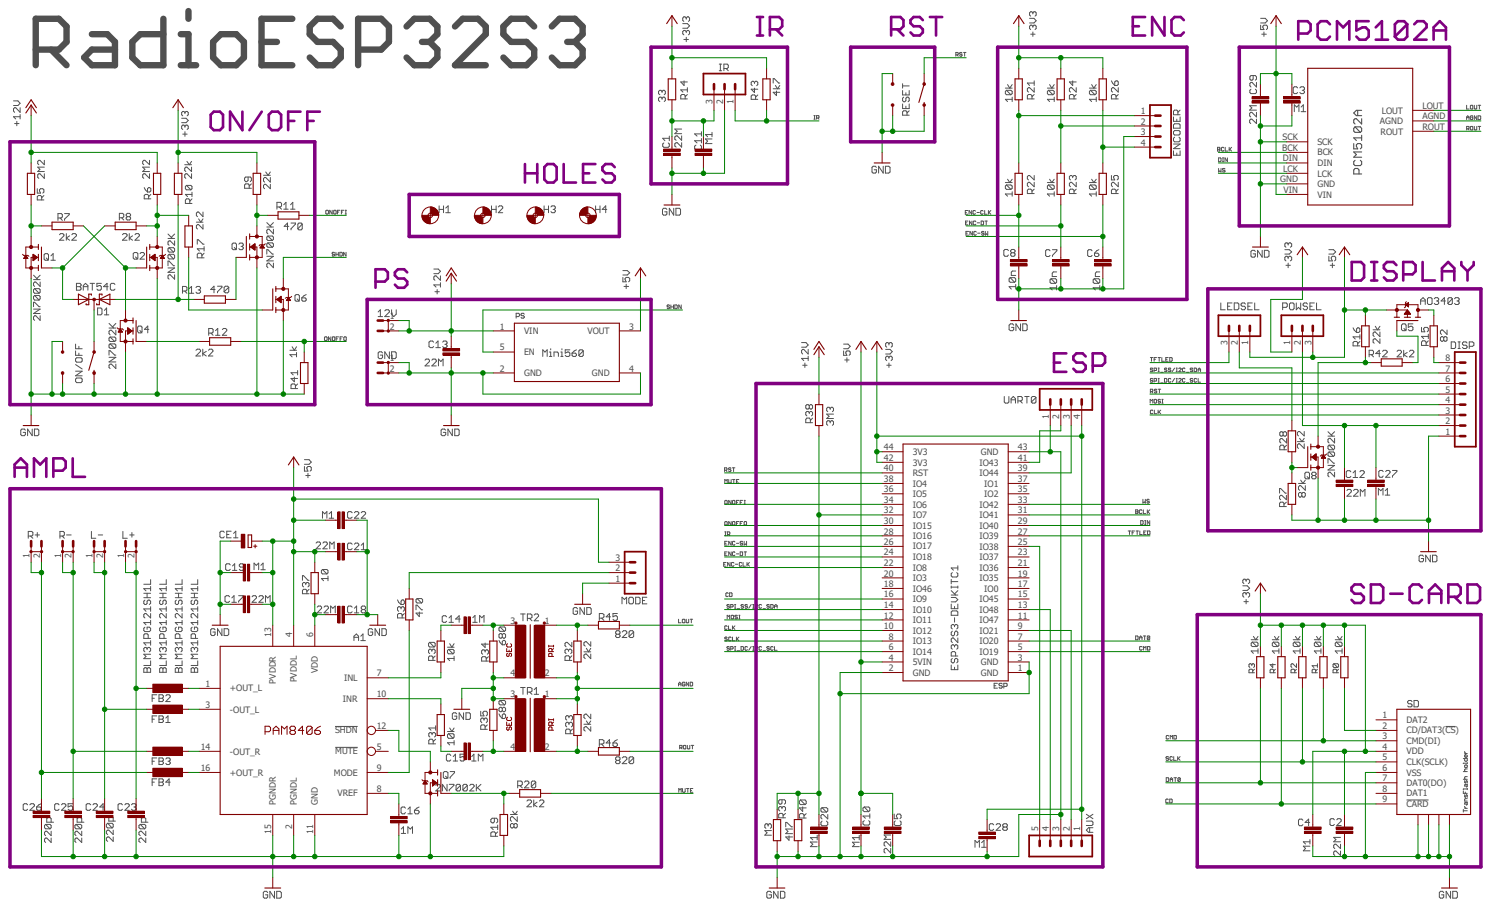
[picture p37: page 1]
CARD; CD/DAT3(CS); CLK(SCLK); CMD(DI); DAT0(DO); DAT1; DAT2; VDD; VSS; GND; 2 GND; VIN; 1 VOUT; INL; INR; 10 VDD ⁶ GND 11; +OUT_R 16; -OUT_R 14; PVDDL 4 PVDDR ¹³; PGNDL 2 PGNDR 15; +OUT_L; -OUT_L; MUTE; SHDN; MODE; VREF; VIN VIN; GND GND; LCK LCK; DIN DIN; BCK BCK; SCK SCK; ROUT; ROUT AGND; AGND LOUT; LOUT 54321; 5VIN; RST 40

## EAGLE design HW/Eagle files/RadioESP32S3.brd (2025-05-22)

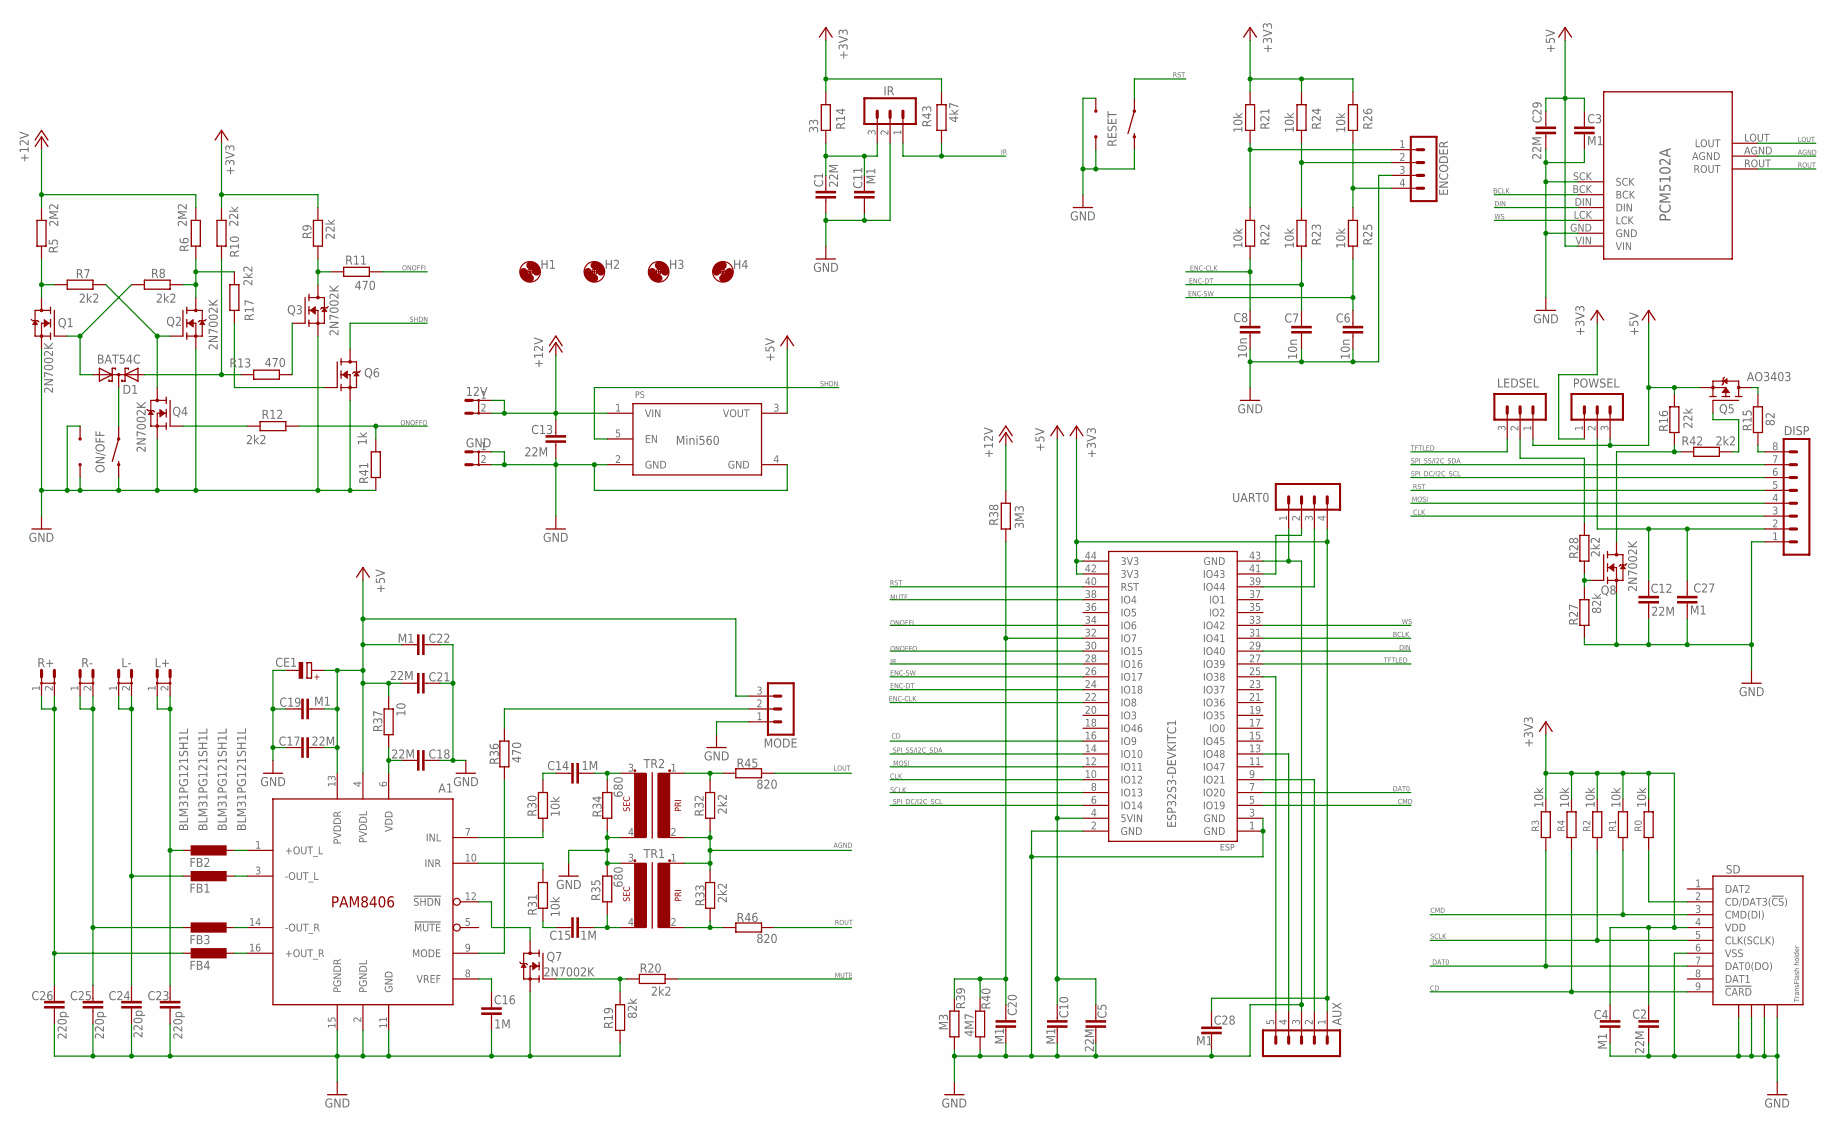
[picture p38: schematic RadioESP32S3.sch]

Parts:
12V: FASTON; FASTON4.8
A1: PAM8406; SOP-16
AUX: CON-LSTB_MA05-108; CON-LSTB_MA05-1-NS08
C1, C2, C5, C12, C13, C17, C18, C21, C29: 22M; C1206K
C3, C4, C10, C11, C19, C20, C22, C27, C28: M1; C0805
C6, C7, C8: 10n; C0805
C14, C15, C16: 1M; C1206K
C23, C24, C25, C26: 220p; C0805
CE1: CPOL; E5-10.5
D1: BAT54C; SOT23
DISP: CON-LSTB_MA08-108; CON-LSTB-MA08-1-NS08
ENCODER: CON-LSTB_MA04-108; CON-LSTB_MA04-1-NS08
ESP: ESP32S3-DEVKITC1
FB1, FB2, FB3, FB4: BLM31PG121SH1L; C1206K
GND: FASTON; FASTON4.8
H1, H2, H3, H4: MOUNT-HOLE3.0; 3,0
IR: CON-LSTB_MA03-108; CON-LSTB_MA03-1-NS08
L+: FASTON; FASTON4.8
L-: FASTON; FASTON4.8
LEDSEL: CON-LSTB_MA03-108; CON-LSTB_MA03-1-NS08
MODE: CON-LSTB_MA03-108; CON-LSTB_MA03-1-NS08
ON/OFF: MOMENTARY-SWITCH-SPST1; TACTILE_SWITCH_ANGLE-NS1
PCM5102A: PCM5102A_MODULE
POWSEL: CON-LSTB_MA03-108; CON-LSTB_MA03-1-NS08
PS: MINI560EXT; MINI560-NS-EXT
Q1, Q2, Q3, Q4, Q6, Q7, Q8: 2N7002K; TRANSISTOR-FET_SOT23
Q5: AO3403; SOT23
R0, R1, R2, R3, R4, R21, R22, R23, R24, R25, R26, R30, R31: 10k; R0805
R5, R6: 2M2; R0805
R7, R8, R12, R17, R20, R28, R32, R33, R42: 2k2; R0805
R9, R10, R16: 22k; R0805
R11, R13, R36: 470; R0805
R14: 33; R0805
R15: 82; R1206
R19, R27: 82k; R0805
R34, R35: 680; R0805
R37: 10; R0805
R38: 3M3; R0805
R39: M3; R0805
R40: 4M7; R0805
R41: 1k; R0805
R43: 4k7; R0805
R45, R46: 820; R0805
R+: FASTON; FASTON4.8
R-: FASTON; FASTON4.8
RESET: MOMENTARY-SWITCH-SPST1; TACTILE_SWITCH_ANGLE-NS1
SD: SD-MMC_TF-HOLDER; SD-MMC_TF-PULL
TR1, TR2: AUDIOTRAFONS2; AUDIOTRAFO_2-NS
UART0: CON-LSTB_MA04-108; CON-LSTB_MA04-1-NS08

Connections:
+3V3: AUX.1, C2.2, C4.2, C28.2, ESP.42 (3V3), ESP.44 (3V3), POWSEL.1, R0.2, R1.2, R2.2, R3.2, R4.2, R9.2, R10.2, R14.2, R21.2, R24.2, R26.2, R43.1, SD.4 (VDD), UART0.4 (5)
+5V: A1.4 (PVDDL), A1.13 (PVDDR), C3.1, C5.1, C10.1, C17.2, C19.2, C21.1, C22.1, C29.2, CE1.+, CE1.++ (+), ESP.4 (5VIN), LEDSEL.1, MODE.3, PCM5102A.VIN, POWSEL.3, PS.3 (VOUT), Q5.2 (S), R16.2, R37.1
+12V: 12V.1, 12V.2, C13.2, PS.1 (VIN), R5.2, R6.2, R38.2
AGND: PCM5102A.AGND, R32.1, R33.2, TR1.1, TR2.2
BCLK: ESP.31 (IO41), PCM5102A.BCK
CD: ESP.16 (IO9), R4.1, SD.9 (!CARD)
CLK: DISP.3, ESP.10 (IO12)
CMD: ESP.5 (IO19), R1.1, SD.3 (CMD(DI))
DAT0: ESP.7 (IO20), R3.1, SD.7 (DAT0(DO))
DIN: ESP.29 (IO40), PCM5102A.DIN
ENC-CLK: C8.1, ESP.22 (IO8), R22.1
ENC-DT: C7.1, ESP.24 (IO18), R23.1
ENC-SW: C6.1, ESP.26 (IO17), R25.1
GND: A1.2 (PGNDL), A1.11 (GND), A1.15 (PGNDR), AUX.3, C1.2, C2.1, C3.2, C4.1, C5.2, C6.2, C7.2, C8.2, C10.2, C11.2, C12.1, C13.1, C16.1, C17.1, C18.2, C19.1, C20.1, C21.2, C22.2, C23.1, C24.1, C25.1, C26.1, C27.2, C28.1, C29.1, CE1.-, DISP.1, ENCODER.3 (4), ESP.1 (GND), ESP.2 (GND), ESP.3 (GND), ESP.43 (GND), GND.1, GND.2, IR.2, MODE.1, ON/OFF.2, ON/OFF.A1, ON/OFF.A2, PCM5102A.GND, PCM5102A.SCK, PS.2 (GND), PS.4 (GND), Q1.2 (S), Q2.2 (S), Q3.2 (S), Q4.2 (S), Q6.2 (S), Q7.2 (S), Q8.2 (S), R19.2, R27.2, R34.1, R35.2, R39.1, R40.1, R41.1, RESET.2, RESET.A1, RESET.A2, SD.6 (VSS), SD.S1, SD.S2, SD.S3, SD.S4, TR1.3 (S1), TR2.4 (S2), UART0.1 (2)
IR: ESP.28 (IO16), IR.1, R43.2
LEDA: DISP.8, R15.1
LOUT: PCM5102A.LOUT, R45.2
MOSI: DISP.4, ESP.12 (IO11)
MUTE: ESP.38 (IO4), R20.1
N31: D1.2 (A2), R10.1, R13.2
unnamed: ESP.39 (IO44), UART0.3 (4)
unnamed: ESP.41 (IO43), UART0.2 (3)
unnamed: C14.1, R34.2, TR2.3 (S1)
unnamed: C15.2, R35.1, TR1.4 (S2)
unnamed: C14.2, R30.2
unnamed: A1.7 (INL), R30.1
unnamed: C15.1, R31.2
unnamed: A1.10 (INR), R31.1
unnamed: C1.1, C11.1, IR.3, R14.1
unnamed: Q2.3 (D), R6.1, R8.1, R17.1
unnamed: Q7.1 (G), R19.1, R20.2
unnamed: R0.1, SD.2 (CD/DAT3(!CS!))
unnamed: Q3.1 (G), R13.1
unnamed: Q1.3 (D), R5.1, R7.2
unnamed: Q5.1 (G), R42.1
unnamed: D1.3 (CC), ON/OFF.1
unnamed: Q2.1 (G), Q4.3 (D), R7.1
unnamed: D1.1 (A1), Q1.1 (G), R8.2
unnamed: Q4.1 (G), R12.2
unnamed: AUX.4, ESP.13 (IO48)
unnamed: Q3.3 (D), R9.1, R11.2
unnamed: AUX.2, ESP.9 (IO21)
unnamed: C12.2, C27.1, DISP.2, POWSEL.2
unnamed: R32.2, R45.1, TR2.1
unnamed: A1.8 (VREF), C16.2
unnamed: A1.12 (!SHDN), Q7.3 (D)
unnamed: A1.9 (MODE), R36.1
unnamed: MODE.2, R36.2
unnamed: C23.2, FB2.2, L+.1, L+.2
unnamed: R33.1, R46.1, TR1.2
unnamed: C25.2, FB3.2, R-.1, R-.2
unnamed: C26.2, FB4.2, R+.1, R+.2
unnamed: A1.1 (+OUT_L), FB2.1
unnamed: A1.3 (-OUT_L), FB1.1
unnamed: A1.14 (-OUT_R), FB3.1
unnamed: A1.16 (+OUT_R), FB4.1
unnamed: Q5.3 (D), R15.2
unnamed: Q8.3 (D), R16.1, R42.2
unnamed: C20.2, ESP.32 (IO7), R38.1, R39.2, R40.2
unnamed: Q6.1 (G), R17.2
unnamed: C24.2, FB1.2, L-.1, L-.2
unnamed: ENCODER.4 (5), R25.2, R26.1
unnamed: ENCODER.2 (3), R23.2, R24.1
unnamed: ENCODER.1 (2), R21.1, R22.2
unnamed: Q8.1 (G), R27.1, R28.1
ONOFFI: ESP.34 (IO6), R11.1
ONOFFO: ESP.30 (IO15), R12.1, R41.2
ROUT: PCM5102A.ROUT, R46.2
RST: DISP.5, ESP.40 (RST), RESET.1
SCLK: ESP.8 (IO13), R2.1, SD.5 (CLK(SCLK))
SHDN: PS.5 (EN), Q6.3 (D)
SPI_DC/I2C_SCL: DISP.6, ESP.6 (IO14)
SPI_SS/I2C_SDA: DISP.7, ESP.14 (IO10)
TFTG: LEDSEL.2, R28.2
TFTLED: ESP.27 (IO39), LEDSEL.3
VDD: A1.6 (VDD), C18.1, R37.2
WS: ESP.33 (IO42), PCM5102A.LCK
XDCS: AUX.5, ESP.25 (IO38)

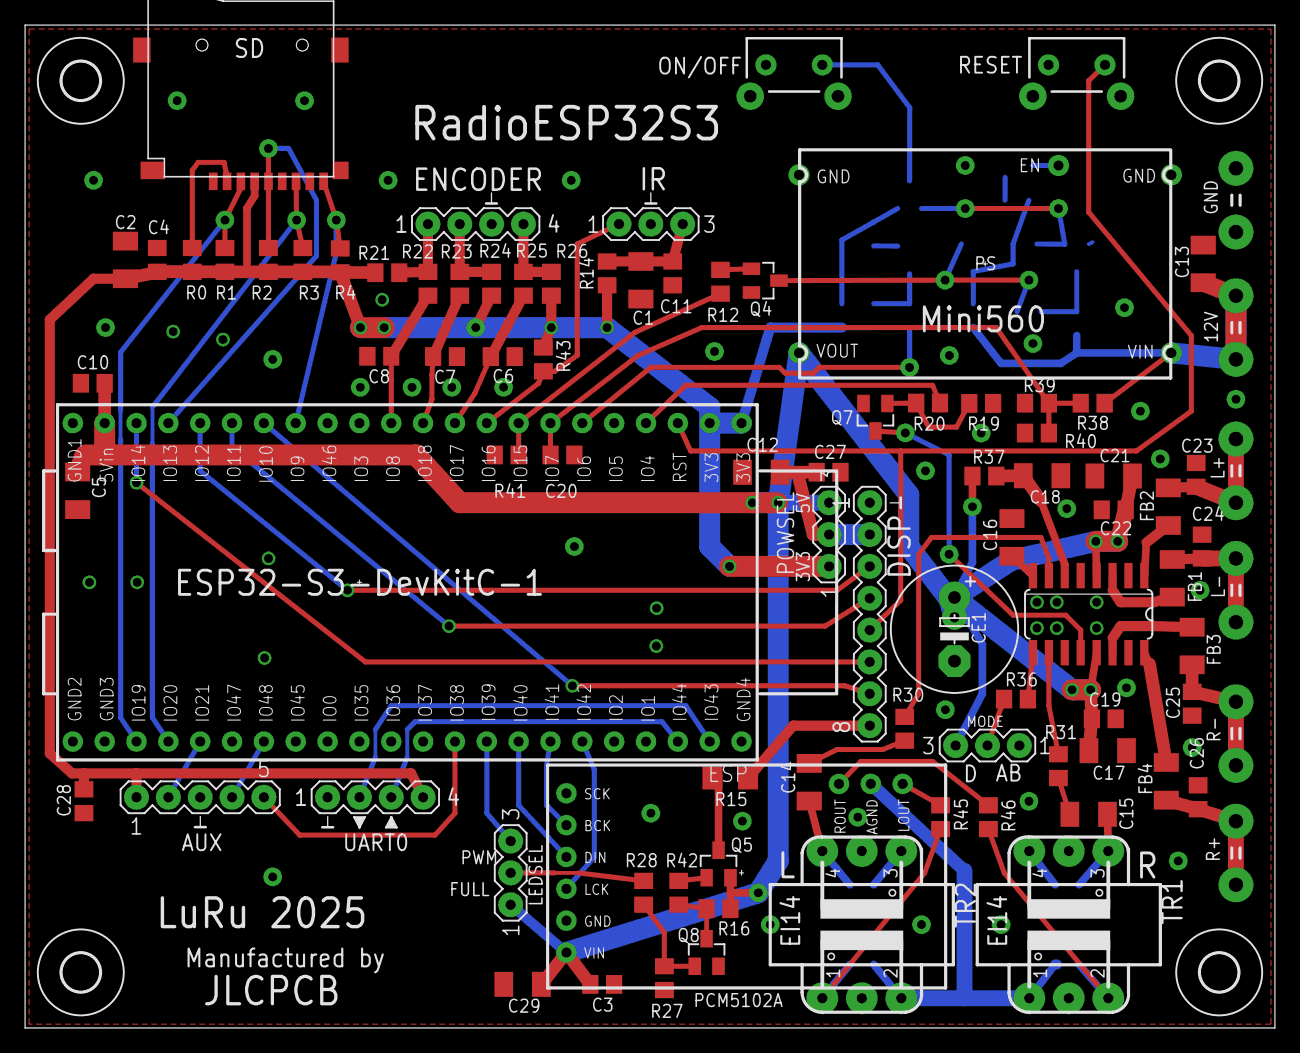
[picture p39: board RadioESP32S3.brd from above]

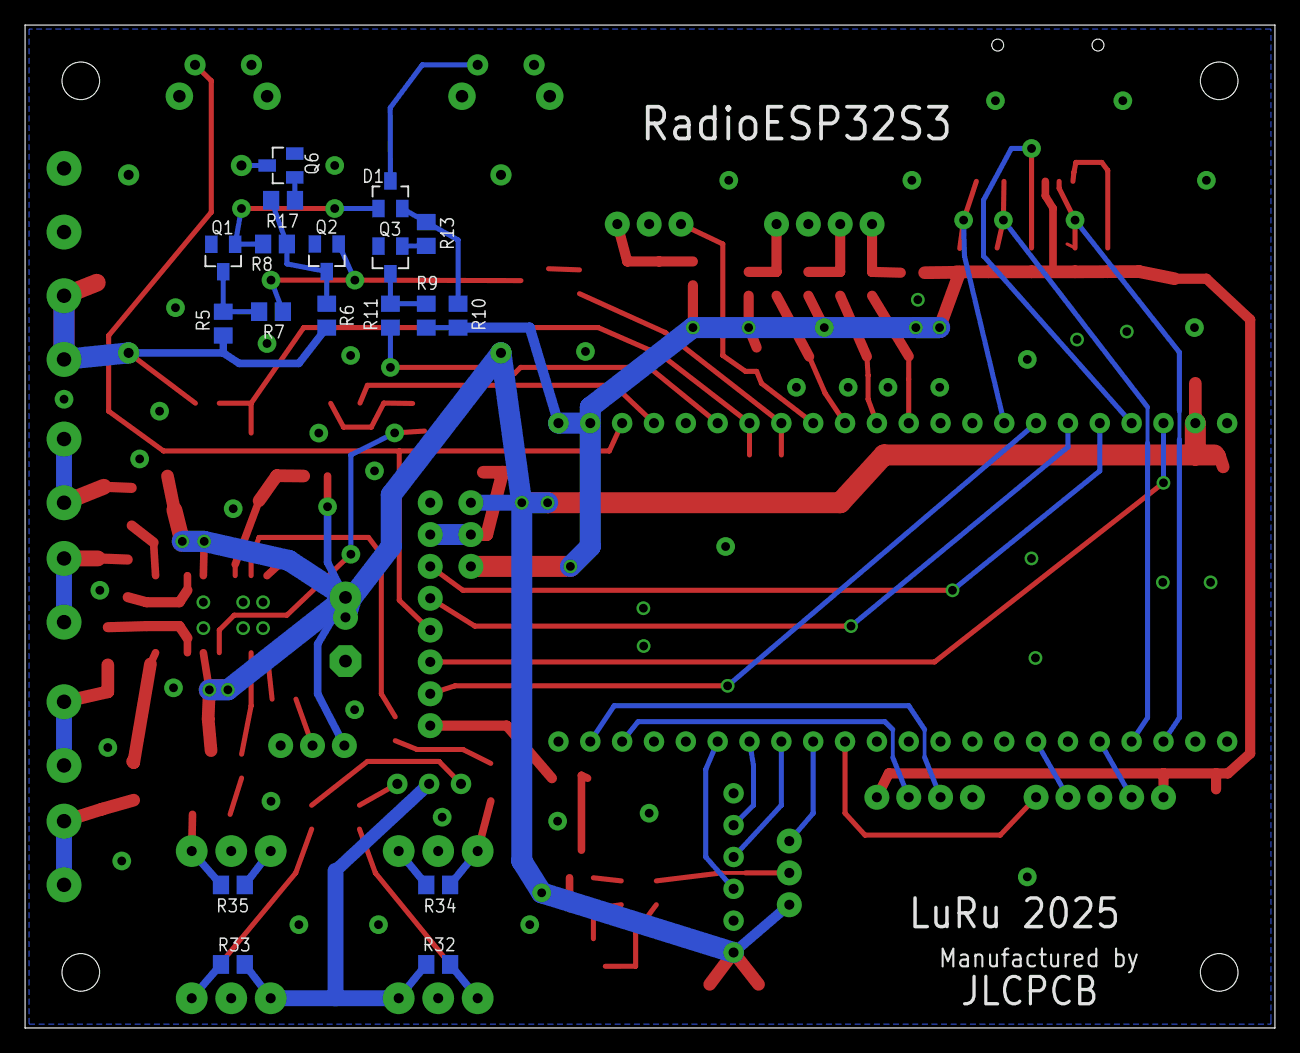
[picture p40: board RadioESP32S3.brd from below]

Board: 2 copper layers, 99.7 x 80.0 mm, 113 parts (18 on the bottom side), 78 nets.

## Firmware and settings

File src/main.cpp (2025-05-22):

#define STR(A) #A
#define STRINGIFY(A) STR(A)
#define REPLACEMENTCHARACTER '*'
#define sv_ DRAM_ATTR static volatile

#include "Arduino.h"
#include <ArduinoJson.h>
#define NO_LED_FEEDBACK_CODE        // saves 92 bytes program memory
#define EXCLUDE_UNIVERSAL_PROTOCOLS // Saves up to 1000 bytes program memory.
#define EXCLUDE_EXOTIC_PROTOCOLS    // saves around 650 bytes program memory if all other protocols are active
#include <IRremote.hpp>
#if defined(DISP)
#include <SPI.h>
#include <TFT_eSPI.h>
#include <u8g2_for_TFT_eSPI.h>
#endif
#include <Wire.h>
#include <ESPmDNS.h>
#include <AsyncTCP.h>
#include <ESPAsyncWebServer.h>
#include <freertos/task.h> // FreeRtos task handling
#include <esp_task_wdt.h>
#include <LittleFS.h>
#if defined(DATAWEB)
#include <FS_editor.h>
#else
// from vendors - fix
#include "webh/glyphicons-halflings-regular.woff.gz.h"
#include "webh/required.css.gz.h"
#include "webh/required.js.gz.h"
// custom, can be updated and changed - generated from files in the LittleFS partition using Custom scripts
#include "webh/radioesp32.js.gz.h"
#include "webh/radioesp32.html.gz.h"
#include "webh/index.html.gz.h"
#endif
#if defined(OTA)
#include <Update.h>
#endif
#include <time.h>
#include "esp_sntp.h"
#include "Audio.h"
#include "esp_log.h"

// Enums and structs
enum mode_wifi
{
  WF_NONE,
  WF_STA,
  WF_WAITSTA
};
mode_wifi WF_MODE = WF_NONE;

enum player_mode
{
  PM_RADIO,
  PM_SDCARD
};

enum player_icons
{
  PI_RADIO,
  PI_SDCARD,
  PI_PLAY,
  PI_PAUSE,
  PI_STOP,
  PI_RANDOM,
  PI_REPEAT,
  PI_MUTE_OFF,
  PI_MUTE_ON
};

struct pi_params
{
  player_icons id;
  uint8_t x;
  uint8_t y;
  uint8_t y2;
  uint8_t idx;
  uint16_t color;
};
struct pi_params *PIparams;

enum IRcmd
{
  IR_0,
  IR_1,
  IR_2,
  IR_3,
  IR_4,
  IR_5,
  IR_6,
  IR_7,
  IR_8,
  IR_9,
  IR_MUTE,
  IR_VOLP,  // volume+
  IR_VOLM,  // volume-
  IR_CHP,   // channel+ (station+)
  IR_CHM,   // channel- (station-)
  IR_PP,    // pause/play
  IR_STOP,  // stop
  IR_RNDM,  // random
  IR_RPT,   // repeat
  IR_RADIO, // radio
  IR_SD,    // SD player
  IR_OK,    // OK
  IR_EX,    // exit
  IR_BS,    // backspace
  IR_FORW,  // next
  IR_BACKW, // previous
#if defined(AUTOSHUTDOWN)
  IR_ISD, // immediate shutdown
  IR_SSD  // scheduled shutdown
#endif
};

#if defined(DISP)
enum disp_mode_t
{
  DSP_RADIO,
  DSP_CLOCK,
  DSP_DIMMED,
  DSP_OFFED,
  DSP_PRESETNR,
  DSP_ASD,   // automatic shut-down set-up
  DSP_PWOFF, // automatic shut-down
  DSP_LOWBATT,
  DSP_OTHER
}; // Display mode status
disp_mode_t dispmode = DSP_OTHER;
#endif

enum enc_menu_t
{
  VOLUME,
  STATIONS,
  TRACKS,
  MODECHANGE,
#if defined(AUTOSHUTDOWN)
  AUTOPWOFF
#endif
}; // State for rotary encoder menu

struct IR_CMD
{
  char descr[25];
  uint32_t ircode;
  IRcmd ircmd;
};

struct WLAN
{
  char name[17];
  uint8_t bssid[6];
  char pass[33];
  char ssid[33];
  uint8_t dhcp;
  IPAddress ipaddress;
  IPAddress subnet;
  IPAddress dnsadd;
  IPAddress gateway;
};

struct PRESET
{
  uint8_t nr = 255; // qsort !!!
  char name[33];
  char url[97];
};

const uint8_t MAXGAP = 16;
#define BUFFLEN (255 - MAXGAP - 2)
#if defined(DISP)
struct RowData
{
  uint8_t ypos;
  char input[BUFFLEN + MAXGAP + 1] = {'\0'};
  char rowmap[BUFFLEN + MAXGAP + 1] = {'\0'};
  uint8_t rowlen;
  uint16_t pixlen = 0;
  uint16_t scrollpos = 0;
  uint8_t lock;
  uint8_t type = 0; // 0-none, 1-plane text, 2-scrolled text, 3-clear
  bool updated = false;
};
#endif

#if defined(SDCARD)
bool sdin = false;
bool oldsdin = false;
#endif

// Forward declaration
void WiFiEvent(WiFiEvent_t, arduino_event_info_t);
#if defined(DISP)
void changeDispMode(disp_mode_t mode);
void volumebar(uint8_t val);
void prgrssbar(uint32_t val, bool clr);
void drawIcon(uint8_t id);
void clearIcons(uint8_t id);
void restoreIcons();
void clearLines();
#endif
#if defined(SDCARD)
void Random();
void Repeat();
void updateTrack(int8_t trckstep);
void setTrack(int16_t trck);
void pausePlay();
void handle_mp3list(AsyncWebServerRequest *request);
#endif
char *cpycharar(char *destination, const char *source, size_t num);
void setPreset(uint8_t prst);
void updatePreset(int8_t prsstep, bool play);
void setMutepin(uint8_t mute_, bool test);
void mute(bool source);
void testUrl(const char *url);
void updateLine(uint8_t row, char *input);

// Global variables
#if defined(SDCARD)
uint32_t pastpos = 0xFFFFFFFF;
uint8_t poscounter = 0;
bool random_ = false;
bool loop_ = true;
#endif
bool sdp_icons_req = false;

#if defined(BATTERY)
#include "hal/adc_types.h"
#include "esp_adc/adc_oneshot.h"

//#include <esp_adc_cal.h>
//#include <esp32-hal-adc.h>


//#define CHANNEL_BAT ADC_CHANNEL_0 // adc1_0, GPIO36
#define CHANNEL_BAT ADC_CHANNEL_6 // GPIO7
adc_oneshot_unit_handle_t adc1_handle;
int adcvalraw = 0;
uint16_t adcval = 0;
bool batbarflag = false;
#define LOG_2(n) ((n == 8) ? 3 : ((n == 16) ? 4 : ((n == 32) ? 5 : 6)))
#define FILTER_LEN 16 // allowed values: 8, 16, 32, 64
const uint8_t FILTER_SHIFT = LOG_2(FILTER_LEN);
const uint8_t FILTER_MASK = FILTER_LEN - 1;
uint16_t *Adc1_Buffer; // PSRAM !
uint8_t Adc1_i = 0;    // Index
uint32_t Sum = 0;
#endif
bool asdmode = false;

#if defined(DISP)
/*
  Fontname: SD_Player
  Copyright: Created with Fony 1.4.0.2
  Glyphs: 7/7
  BBX Build Mode: 0
*/
const uint8_t PROGMEM SD_player[211] U8G2_FONT_SECTION("SD_player") =
    "\11\0\4\3\4\4\4\3\5\17\17\0\0\0\0\0\0\0\0\0\0\0\266\0\25\333\332\17A)b\222"
    "\304d\222*\42YD\272\311\320\274\2\1\35\277\350O\42\67\7\7#\63\26Z\264\220\60\231\220\70\210"
    "PQ\241\205\311\314\301\7\4\2\23\327\334\17aRC\64%\26\7\26%\64CRa\0\3\11\270\353"
    "\17#\376O\6\4\11\273\352\17\377\377\7\2\5\33\337\330\317\341\22s\65Q!R\61\351\42\242S\304"
    "\306\244J\42\61W,\35\2\6\32\317\350/\7D\221A\221Aq\265\323A\321\263uA\221A\221A"
    "\7$\0\7\21\370\313\177aRC\24\7\177PqD\65&\27\10\27\370\313\177aR\21A!\21\63"
    "b:\213\230\11\12\211\212\10\223\13\0\0\0\4\377\377\0";

TFT_eSPI tft = TFT_eSPI(); // tft instance
U8g2_for_TFT_eSPI u8g2;    // u8f2 font instance
U8g2_for_TFT_eSPI u8h2[3]; // u8f2 font instance for rows
TFT_eSprite sprite[3] = {TFT_eSprite(&tft), TFT_eSprite(&tft), TFT_eSprite(&tft)};
TFT_eSprite volsprite = TFT_eSprite(&tft);
uint16_t *volsprPtr;
TFT_eSprite prgrsssprite = TFT_eSprite(&tft);
uint16_t *prgrsssprPtr;
#if defined(BATTERY)
TFT_eSprite batsprite = TFT_eSprite(&tft);
uint16_t *batsprPtr;
#endif
const int freq = 500;
const int resolution = 8;
#endif
const char SPACES[33] = "                                ";
char *shorttrname;
#if defined(DISP)
const uint8_t *font = u8g2_font_t0_22_me;
const uint8_t *rowfont = font;
struct RowData *rows;
bool volbarflag = false;
bool prgrssbarflag = false;
int16_t oldprgrssw = -1;
int8_t dispmuteflag = -1;
bool scrollpair = false;
uint8_t xshift = 2; // display scroll step
uint32_t lastblick;
bool coloncolor = false;

const char gaps[MAXGAP + 1] = "                ";
uint32_t lastredrw;
uint32_t textcolor = 1;
uint32_t backcolor = 0;
char oldtimetxt[6];  // Converted timeinfo
char olddatetxt[16]; // Converted timeinfo/date
#else
const char gaps[1] = "";
#endif

struct WLAN *wlans;
struct PRESET *presets;

const char cmd_0[] PROGMEM = "Digit 0";
const char cmd_1[] PROGMEM = "Digit 1";
const char cmd_2[] PROGMEM = "Digit 2";
const char cmd_3[] PROGMEM = "Digit 3";
const char cmd_4[] PROGMEM = "Digit 4";
const char cmd_5[] PROGMEM = "Digit 5";
const char cmd_6[] PROGMEM = "Digit 6";
const char cmd_7[] PROGMEM = "Digit 7";
const char cmd_8[] PROGMEM = "Digit 8";
const char cmd_9[] PROGMEM = "Digit 9";
const char cmd_10[] PROGMEM = "Mute";
const char cmd_11[] PROGMEM = "Volume+";
const char cmd_12[] PROGMEM = "Volume-";
const char cmd_13[] PROGMEM = "Channel+";
const char cmd_14[] PROGMEM = "Channel-";
const char cmd_15[] PROGMEM = "Pause/Play";
const char cmd_16[] PROGMEM = "Stop";
const char cmd_17[] PROGMEM = "Random";
const char cmd_18[] PROGMEM = "Repeat";
const char cmd_19[] PROGMEM = "Radio";
const char cmd_20[] PROGMEM = "SD_player";
const char cmd_21[] PROGMEM = "OK";
const char cmd_22[] PROGMEM = "Exit";
const char cmd_23[] PROGMEM = "Backspace";
const char cmd_24[] PROGMEM = "Step Forward";
const char cmd_25[] PROGMEM = "Step Backward";
#if defined(AUTOSHUTDOWN)
const char cmd_26[] PROGMEM = "Power OFF";
const char cmd_27[] PROGMEM = "Sleep";
#endif
const char *const cmd_table[] PROGMEM =
    {
        cmd_0,
        cmd_1,
        cmd_2,
        cmd_3,
        cmd_4,
        cmd_5,
        cmd_6,
        cmd_7,
        cmd_8,
        cmd_9,
        cmd_10,
        cmd_11,
        cmd_12,
        cmd_13,
        cmd_14,
        cmd_15,
        cmd_16,
        cmd_17,
        cmd_18,
        cmd_19,
        cmd_20,
        cmd_21,
        cmd_22,
        cmd_23,
        cmd_24,
        cmd_25,
#if defined(AUTOSHUTDOWN)
        cmd_26,
        cmd_27
#endif
};
#if defined(AUTOSHUTDOWN)
const uint8_t cmd_table_len = 28;
#else
const uint8_t cmd_table_len = 26;
#endif
uint8_t *RESERVEDGPIOS;
struct IR_CMD *ir_cmds;
char *testurl;
int Weekday;
uint8_t irnum = 0;
uint8_t presetnum = 0;
uint8_t wlannum = 0;
bool shouldReboot = false;
bool formatreq = false;

/*
Username and password are used in two cases:
============================================
1. to enter the website editor
2. when updating firmware
*/
const char *http_username = "admin";
const char *http_password = "admin";

Audio audio;
TaskHandle_t Task0, xsdtask, maintask;

#define FSIF true // Format LittleFS if not existing
bool STAmode = true;
bool APstart = false;
bool gotIP = false;
uint8_t scanmode = 0;
bool clockReq = false;
unsigned long digtime = 0;
uint16_t idleTimer = 0;
uint16_t dgt_inactivity = 255; // Digit input inactive
uint8_t dgt_count = 0;         // Digit input count
uint16_t dgt_cmd;              // Buffer for digit input

#if defined(AUTOSHUTDOWN)
uint16_t dgt_asd;          // Buffer for digit input for AUTOSHUTDOWN
uint8_t dgt_count_asd = 0; // Digit input count
#define MAXPWOFF 100
#define MINPWOFF 1
bool pwoff_req = false; // Set on/off requested
bool fade_req = false;  // Set fade requested
uint32_t lastfade = 0;
uint16_t pwoffminutes = MAXPWOFF; // Current power off [minutes] duration
time_t pwofftime = 0;
time_t now;
#endif
bool digitsReq = false;
uint8_t presetReq = 255;
bool testurlFlag = false;
uint16_t reqpreset = 255;
uint16_t audpreset = 255;
bool reconnect = false;
bool rcnnct = false;
bool scanfinished = false;
bool muteflag = false; // Mute output
uint8_t reqvol = 12;   // Requested volume
player_mode pmode = PM_RADIO;
int16_t nets;
AsyncWebServer server(80);
AsyncWebSocket weso("/ws");

#if defined(SDCARD)
int SD_curindex = 0;     // Current index in mp3names
int SD_ix = 0;           // work index in mp3names
bool SD_okay = false;    // SD is okay
bool SD_mounted = false; // SD is mounted
int SD_filecount = 0;    // Number of filenames in SD_nodelist
int SD_oldindex = 0;
bool sdready_req = false;
bool oldsdix_req = false;
#endif

#if defined(DISP)
uint8_t WID = 160;
uint8_t HGT = 128;
uint8_t LINEOFFSET = 17;
uint8_t ROW_LEN = 14;
uint8_t CELLWID = 11;
uint8_t CELLHGT = 22;
uint8_t ROWSNUM = 3;
#else // NO DISPLAY
#define ROWSNUM 0
#define MAXGAP 0
#define ROW_LEN 0
// uint8_t ROWSNUM = 0;
#endif
char *station; //  PSRAM !
char *artist;  //  PSRAM !
char *title;   //  PSRAM !
bool updatemetadata = false;
bool updatealbum = false;
bool updateartist = false;
bool updatetitle = false;
uint8_t messageid = 0;

#include "config.h"
Config *config;
#include "loadConfig.h"
#include "wsResponses.h"
#include "websocket.h"
#include "webserver.h"
#if defined(SDCARD)
#include "SDcard.h" // For SD card interface
#endif

const char *TAG = "main"; // For debug lines

char timetxt[9];  // Converted timeinfo
char datetxt[16]; // Converted timeinfo/date

bool time_req = false;   // Set time requested
bool proc1s_req = false; // Set proc1s requested
bool proc5s_req = false; // Set proc5s requested
struct tm timeinfo;      // Will be filled by NTP server
unsigned long currentMillis = 0;
float btvol = 0.12;       // Bluetooth volume
hw_timer_t *timer = NULL; // For timer

// Rotary encoder stuff
int16_t enc_preset = 0;      // Selected preset
uint16_t enc_inactivity = 0; // Time inactive
uint16_t clickcount = 0;     // Incremented per encoder click
int16_t rotationcount = 0;   // Current position of rotary switch
bool singleclick = false;    // True if single click detected: MUTE or ENTER
bool doubleclick = false;    // True if double click detected: STATION mode
bool tripleclick = false;    // True if triple click detected: TRACK mode
bool longclick = false;      // True if longclick detected:    reboot request mode

#if defined(AUTOSHUTDOWN)
bool pwoffclick = false; // True if power off click detected
#endif
#define DIR_CW 0x10  // Clockwise step.
#define DIR_CCW 0x20 // Anti-clockwise step.
#define R_START 0x0
#define F_CW_FINAL 0x1
#define F_CW_BEGIN 0x2
#define F_CW_NEXT 0x3
#define F_CCW_BEGIN 0x4
#define F_CCW_FINAL 0x5
#define F_CCW_NEXT 0x6
uint8_t table_state; // Internal state
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
void loop()
{
  char timetxt2[9];
  char shorttimetxt[6];
  char sub[3];
  uint32_t now_;
  uint8_t ix;
  if (gotIP)
  {
    WF_MODE = WF_STA;
#if defined(DISP)
    dispmode = DSP_OTHER;
    tft.fillScreen(TFT_BLACK);
    u8g2.setFont(u8g2_font_t0_17_me);
    uint8_t offset = 6 + u8g2.getFontDescent() + u8g2.getFontAscent();
    uint8_t linehgt = offset + 15;
    u8g2.setForegroundColor(TFT_WHITE);
    char charbuf[24];
    sprintf(charbuf, "RadioESP32S3 %s", STRINGIFY(VERSION));
    drawUTF8(0, offset, charbuf);
    drawUTF8(0, linehgt + offset, "SSID:");
    drawUTF8(0, 2 * linehgt + offset - 8, WiFi.SSID().c_str());
    drawUTF8(0, 3 * linehgt + offset, "IP Address:");
    IPAddress ip = WiFi.localIP();
    sprintf(charbuf, "%d.%d.%d.%d", ip[0], ip[1], ip[2], ip[3]);
    drawUTF8(0, 4 * linehgt + offset - 8, charbuf);
#endif
    if (reconnect)
    {
      vTaskDelay(8000 / portTICK_PERIOD_MS);
      if (pmode == PM_RADIO)
      {
        audpreset = 254;
      }
      reconnect = false;
    }
    else
    {
      vTaskDelay(4000 / portTICK_PERIOD_MS);
      reqpreset = enc_preset;
    }
    setMutepin(0, false);
#if defined(DISP)
    changeDispMode(DSP_RADIO);
#endif
    if (pmode == PM_RADIO)
    {
      char nr[6];
      sprintf(nr, "[%02d] ", presets[enc_preset].nr);
      cpycharar(station, nr, 5);
      cpycharar(station + 5, presets[enc_preset].name, BUFFLEN - 6);
#if defined(DISP)
      show_station(station);
#endif
    }
    gotIP = false;
  }
  if (APstart)
  {
#if defined(DISP)
    u8g2.setFont(u8g2_font_t0_17_me);
    u8g2.setBackgroundColor(TFT_BLACK);
    u8g2.setForegroundColor(TFT_WHITE);
    uint8_t offset = 6 + u8g2.getFontDescent() + u8g2.getFontAscent();
    uint8_t linehgt = offset + 15;
    char charbuf[24];
    sprintf(charbuf, "RadioESP32S3 %s", STRINGIFY(VERSION));
    drawUTF8(0, offset, charbuf);
    u8g2.setBackgroundColor(TFT_WHITE);
    u8g2.setForegroundColor(TFT_BLACK);
    drawUTF8(0, linehgt + offset, "AP SSID:");
    drawUTF8(0, 2 * linehgt + offset - 8, WiFi.softAPSSID().c_str());
    drawUTF8(0, 3 * linehgt + offset, "AP IP Address:");
    IPAddress ip = WiFi.softAPIP();
    sprintf(charbuf, "%d.%d.%d.%d", ip[0], ip[1], ip[2], ip[3]);
    drawUTF8(0, 4 * linehgt + offset - 8, charbuf);
    u8g2.setBackgroundColor(TFT_BLACK);
    u8g2.setForegroundColor(TFT_WHITE);
#endif
    APstart = false;
  }
  if (clockReq)
  {
#if defined(DISP)
#if defined(AUTOSHUTDOWN)
    if (pwofftime > 0)
    {
      changeDispMode(DSP_PWOFF);
    }
    else
    {
#endif
      switch (config->tmode)
      {
      case 3:
        changeDispMode(DSP_CLOCK);
        break;
      case 2:
        changeDispMode(DSP_DIMMED);
        break;
      case 1:
        changeDispMode(DSP_OFFED);
        break;
      default:
        break;
      }
#if defined(AUTOSHUTDOWN)
    }
#endif
#endif
    clockReq = false;
  }

  chk_enc(); // Check rotary encoder functions
  if (updatemetadata)
  {
    if (enc_menu_mode == VOLUME)
    {
#if defined(DISP)
      show_title(title);
      show_artist(artist);
#endif
    }
#if defined(DISP)
#if defined(AUTOSHUTDOWN)
    if (dispmode != DSP_ASD)
    {
#endif
      changeDispMode(DSP_RADIO);
#if defined(AUTOSHUTDOWN)
    }
#endif
#endif
    if (pmode == PM_RADIO)
    {
      sendRadio();
    }
#if defined(SDCARD)
    else
    {
      sendSDplayer(3); // useful for .ogg tracks !!!
    }
#endif
    updatemetadata = false;
  }
  if (updatealbum)
  {
    if (enc_menu_mode == VOLUME)
    {
#if defined(DISP)
      show_station(station);
#endif
    }
#if defined(DISP)
#if defined(AUTOSHUTDOWN)
    if (dispmode != DSP_ASD)
    {
#endif
      changeDispMode(DSP_RADIO);
#if defined(AUTOSHUTDOWN)
    }
#endif
#endif
#if defined(SDCARD)
    sendSDplayer(0);
#endif
    updatealbum = false;
  }
  if (updateartist)
  {
    if (enc_menu_mode == VOLUME)
    {
#if defined(DISP)
      show_artist(artist);
#endif
    }
#if defined(DISP)
#if defined(AUTOSHUTDOWN)
    if (dispmode != DSP_ASD)
    {
#endif
      changeDispMode(DSP_RADIO);
#if defined(AUTOSHUTDOWN)
    }
#endif
#endif
#if defined(SDCARD)
    sendSDplayer(1);
#endif
    updateartist = false;
  }
  if (updatetitle)
  {
    if (enc_menu_mode == VOLUME)
    {
#if defined(DISP)
      show_title(title);
#endif
    }
#if defined(DISP)
#if defined(AUTOSHUTDOWN)
    if (dispmode != DSP_ASD)
    {
#endif
      changeDispMode(DSP_RADIO);
#if defined(AUTOSHUTDOWN)
    }
#endif
#endif
#if defined(SDCARD)
    sendSDplayer(2);
#endif
    updatetitle = false;
  }
#if defined(DISP)
  if (time_req)
  {
    gettime(); // update timetxt (mandatory for big clock !)
    if (WiFi.status() == WL_CONNECTED)
    {
      time_req = false;
      if ((dispmode == DSP_RADIO) || (dispmode == DSP_DIMMED))
      {
#if defined(DISP)
        u8g2.setFont(u8g2_font_t0_17_mn); // time font
#if defined(AUTOSHUTDOWN)
        if (pwofftime > 0)
        {
          time(&now);
          uint32_t pwofft = pwofftime - now;
          u8g2.setForegroundColor(TFT_RED);
          secondsToHMS(pwofft, timetxt2);
          drawStr(WID - 8 * 9, 21, timetxt2);
          u8g2.setForegroundColor(TFT_WHITE);
        }
        else
        {
#endif
          if (config->sdclock && pmode == PM_SDCARD)
          {
            uint32_t remtime = audio.getAudioFileDuration() - audio.getAudioCurrentTime();
            u8g2.setForegroundColor(TFT_YELLOW);
            secondsToHMS(remtime, timetxt2);
            drawStr(WID - 8 * 9, 21, timetxt2);
            u8g2.setForegroundColor(TFT_WHITE);
          }
          else
          {
            u8g2.setForegroundColor(TFT_WHITE);
            drawStr(WID - 8 * 9, 21, timetxt);
          }
#if defined(AUTOSHUTDOWN)
        }
#endif
#endif
      }
      else if (dispmode == DSP_CLOCK)
      {
        cpycharar(shorttimetxt, timetxt, 5);
        if ((strcmp(shorttimetxt, oldtimetxt) != 0) || (strcmp(datetxt, olddatetxt) != 0))
        {
          cpycharar(olddatetxt, datetxt, 15);
          cpycharar(oldtimetxt, shorttimetxt, 5);
#if defined(DISP)
          u8g2.setFont(u8g2_font_inb42_mn);
          u8g2.setForegroundColor(TFT_WHITE);
          cpycharar(sub, timetxt, 2);
          uint8_t cw = u8g2.getUTF8Width(sub);
          uint8_t colw = min(cw / 2, (WID - 2 * cw));
          drawStr((WID - colw) / 2 - cw, HGT - 1, sub);
          cpycharar(sub, timetxt + 3, 2);
          drawStr((WID + colw) / 2, HGT - 1, sub);
          if (config->calendar)
          {
            u8g2.setFont(u8g2_font_inr19_mn);
            drawStr(0, 24, datetxt);
            u8g2.setFont(font);
            cw = u8g2.getUTF8Width(config->wdays[Weekday]);
            u8g2.drawUTF8((WID - cw) / 2, 60, config->wdays[Weekday]);
          }
#endif
        }
      }
#if defined(AUTOSHUTDOWN)
      else if (dispmode == DSP_PWOFF)
      {
        if (pwofftime > 0)
        {
          time(&now);
          uint32_t pwofft = pwofftime - now;
          sprintf(timetxt2, "%02d:%02d", pwofft / 60, pwofft % 60); // format new remaining time
                                                                    // u8g2.drawStr(WID - 8 * 9, 21, timetxt2);
#if defined(DISP)
          u8g2.setForegroundColor(TFT_RED);
          u8g2.setFont(u8g2_font_inb42_mn);
          cpycharar(sub, timetxt2, 2);
          uint8_t cw = u8g2.getUTF8Width(sub);
          uint8_t colw = min(cw / 2, (WID - 2 * cw));
          drawStr((WID - colw) / 2 - cw, HGT - 1, sub);
          cpycharar(sub, timetxt2 + 3, 2);
          drawStr((WID + colw) / 2, HGT - 1, sub);
#endif
        }
      }
#endif
    }
  }
  if ((dispmode == DSP_RADIO) || (dispmode == DSP_DIMMED))
  {
    displayloop();
  }

  if (((config->tmode > 0) && (dispmode == DSP_CLOCK)) || (dispmode == DSP_PWOFF))
  {
    // colon blick
    now_ = millis();
    if (now_ - lastblick > 500)
    {
      lastblick = now_;
      coloncolor = !coloncolor;
      drawColon(coloncolor);
    }
  }
#if defined(DISP)
  if (sdp_icons_req)
  {
    sdp_icons();
    sdp_icons_req = false;
  }
#endif
#endif
  if (proc1s_req)
  {
#if defined(SDCARD)
    if (pmode == PM_SDCARD)
    {
      if (audio.isRunning())
      {
        uint32_t pstn = audio.getAudioCurrentTime();
        if (pstn == pastpos)
        {
          if (poscounter++ == 8)
          {
            poscounter = 0;
            pastpos = 0xFFFFFFFF;
            handleEOF();
          }
        }
        else
        {
          pastpos = pstn;
          poscounter = 0;
          if (weso.count() > 0)
          {
            sendSDstat(pstn);
#if defined(DISP)
            prgrssbar(pstn, false);
#endif
          }
        }
      }
    }
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

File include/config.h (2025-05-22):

struct Config {
	bool default_ = 1;
	uint8_t defvol = 16;
	int8_t bass = 0;
	int8_t mid = 0;
	int8_t treble = 0;
	uint8_t defstat = 0;
	uint8_t seekstep = 30;
    char hostnm[24] = "RadioESP32S3";
    char ntpServer[24] = "pool.ntp.org";
	int ntpInterval = 15;
    char timeZone[40] = "CET-1CEST,M3.5.0,M10.5.0/3";
    char tzname[24] = "Europe/Prague";
    char dateformat[11] = "dd-mm-yyyy";
	uint8_t backlight1 = 150;
	uint8_t backlight2 = 0;
	uint16_t refr = 100;
	uint8_t scrollgap = 5;
	uint16_t idle = 30;
	uint8_t tmode = 1;
#if defined(BATTERY)
	uint16_t bat0 = 4094;
	uint16_t bat100 = 4095;
	uint8_t lowbatt = 0;
	uint8_t critbatt = 10;
	uint16_t batw = 1000;
	bool batenabled = false;
#endif
	uint8_t sdclock = 1;
	uint8_t calendar = 0;
	uint8_t bclkpin = 255;
	uint8_t doutpin = 255;
	uint8_t wspin = 255;
#if defined(DISP)
	uint8_t dsptype = 0;
	uint8_t angle = 0;
	uint8_t bckpin = 255;
	uint8_t bckinv = 0;
#endif
	uint8_t extpullup = 0;
#if defined(SDCARD)
	uint8_t sdpullup = 0;
	uint8_t sdclkpin = 255;
	uint8_t sdcmdpin = 255;
	uint8_t sdd0pin = 255;
	uint8_t sddpin = 255;
#endif
	uint8_t encclkpin = 255;
	uint8_t encdtpin = 255;
	uint8_t encswpin = 255;
	uint8_t irpin = 255;
	uint8_t mutepin = 255;
#if defined(AUTOSHUTDOWN)
	uint8_t onoffipin = 255;
	uint8_t onoffopin = 255;
	uint8_t dasd = 20;
#endif
    IPAddress apaddress = {192, 168, 4, 1};
    IPAddress apsubnet = {255, 255, 255, 0};
    char apssid[33] = "RadioESP32S3";
    char wdays[7][24];
};

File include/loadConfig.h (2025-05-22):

const char *LCTAG = "loadConfig"; // For debug lines
#include "base64.hpp"

void decodeB64(const char *inputStr, char *output)
{
	unsigned char ibuff[65];
	memcpy(ibuff, inputStr, 65);
	unsigned char obuff[33];
	// decode_base64() does not place a null terminator, because the output is not always a string
	unsigned int string_length = decode_base64(ibuff, obuff);
	obuff[string_length] = '\0';
	memcpy(output, obuff, string_length + 1);
}

// used by qsort to sort presets
int cmpfunc(const void *a, const void *b)
{
	PRESET *presetA = (PRESET *)a;
	PRESET *presetB = (PRESET *)b;
	return (presetA->nr - presetB->nr);
}

bool loadConfiguration(Config *config)
{
	uint8_t resix = 0;
#if defined(SDCARD)
	//RESERVEDGPIOS[resix++] = 2;
	//RESERVEDGPIOS[resix++] = 14;
	//RESERVEDGPIOS[resix++] = 15;
#endif
#if defined(BOARD_HAS_PSRAM)
	//RESERVEDGPIOS[resix++] = 16;
	//RESERVEDGPIOS[resix++] = 17;
#endif
#if defined(DISP)
	RESERVEDGPIOS[resix++] = 10;
	RESERVEDGPIOS[resix++] = 11;
	RESERVEDGPIOS[resix++] = 12;
	RESERVEDGPIOS[resix++] = 14;
#endif
#if defined(BATTERY)
	RESERVEDGPIOS[resix++] = 7;
#endif
	// ToDo for other display versions ?
	File configFile = LittleFS.open("/config.json", "r");
	if (!configFile)
	{
		ESP_LOGW(LCTAG, "Failed to open config file");
		return false;
	}
	size_t size = configFile.size();
	std::unique_ptr<char[]> buf(new char[size]);
	configFile.readBytes(buf.get(), size);
	JsonDocument json;
	auto error = deserializeJson(json, buf.get());
	if (error)
	{
		ESP_LOGW(LCTAG, "Failed to parse config file");
		return false;
	}
	ESP_LOGW(LCTAG, "Config file found");
	ESP_LOGW(LCTAG, "Trying to setup rotary encoder hardware");
	config->default_ = json["default"];
	JsonObject hardware = json["hardware"];
#if defined(SDCARD)
	JsonObject sdplayer = json["sdplayer"];
	if (sdplayer["seekstep"].is<uint8_t>())
	{
		config->seekstep = sdplayer["seekstep"];
	}
	if (hardware["sdclkpin"].is<uint8_t>())
	{
		config->sdclkpin = hardware["sdclkpin"];
	}
	if (hardware["sdcmdpin"].is<uint8_t>())
	{
		config->sdcmdpin = hardware["sdcmdpin"];
	}
	if (hardware["sdd0pin"].is<uint8_t>())
	{
		config->sdd0pin = hardware["sdd0pin"];
	}
	uint8_t sdmode = (config->sdpullup == 1) ? INPUT : INPUT_PULLUP;
	if (hardware["sddpin"].is<uint8_t>())
	{
		config->sddpin = hardware["sddpin"];
		if (config->sddpin != 255)
		{
			pinMode(config->sddpin, sdmode);
		}
	}
#endif
	if (hardware["extpullup"].is<uint8_t>())
	{
		config->extpullup = hardware["extpullup"];
	}
	uint8_t pinmode = (config->extpullup == 1) ? INPUT : INPUT_PULLUP;
	ESP_LOGW(LCTAG, "Rotary encoder pin mode = \"%s\"", (pinmode == INPUT) ? "INPUT" : "INPUT_PULLUP");
	if (hardware["encswpin"].is<uint8_t>())
	{
		config->encswpin = hardware["encswpin"];
		if (config->encswpin != 255)
		{
			pinMode(config->encswpin, pinmode);
		}
	}
	JsonArray ircmds = json["irremote"]["commands"];
	JsonObject general = json["general"];
	JsonObject display = json["display"];
#if defined(AUTOSHUTDOWN)
	config->dasd = general["dasd"];
#endif
#if defined(BATTERY)
	config->bat0 = general["bat0"];
	config->bat100 = general["bat100"];
	config->batw = config->bat100 - config->bat0;
	config->lowbatt = general["lowbatt"];
	config->critbatt = general["critbatt"];
	config->batenabled = ((config->bat100 <= 4095) && (config->bat0 < (config->bat100-1)));
#endif
	if (hardware["encclkpin"].is<uint8_t>())
	{
		config->encclkpin = hardware["encclkpin"];
		if (config->encclkpin != 255)
		{
			pinMode(config->encclkpin, pinmode);
		}
	}
	if (hardware["encdtpin"].is<uint8_t>())
	{
		config->encdtpin = hardware["encdtpin"];
		if (config->encdtpin != 255)
		{
			pinMode(config->encdtpin, pinmode);
		}
	}
	if (hardware["mutepin"].is<uint8_t>())
	{
		config->mutepin = hardware["mutepin"];
		if (config->mutepin != 255)
		{
			pinMode(config->mutepin, OUTPUT);
			digitalWrite(config->mutepin, HIGH); // turn off (mute) the amplifier until everything is ready
		}
	}
#if defined(AUTOSHUTDOWN)
	if (hardware["onoffipin"].is<uint8_t>())
	{
		config->onoffipin = hardware["onoffipin"];
	}
	if (hardware["onoffopin"].is<uint8_t>())
	{
		config->onoffopin = hardware["onoffopin"];
		if (config->onoffopin != 255)
		{
			pinMode(config->onoffopin, OUTPUT);
			digitalWrite(config->onoffopin, LOW);
		}
	}
#endif
	if (hardware["irpin"].is<uint8_t>())
	{
		config->irpin = hardware["irpin"];
	}
#if defined(DISP)
	if (hardware["angle"].is<uint8_t>())
	{
		config->angle = hardware["angle"];
	}
	config->dsptype = 128; // ToDo for other DISP drivers
	if (hardware["bckpin"].is<uint8_t>())
	{
		config->bckpin = hardware["bckpin"].as<uint8_t>();
	}
	if (hardware["bckinv"].is<uint8_t>())
	{
		config->bckinv = hardware["bckinv"].as<uint8_t>();
	}
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
